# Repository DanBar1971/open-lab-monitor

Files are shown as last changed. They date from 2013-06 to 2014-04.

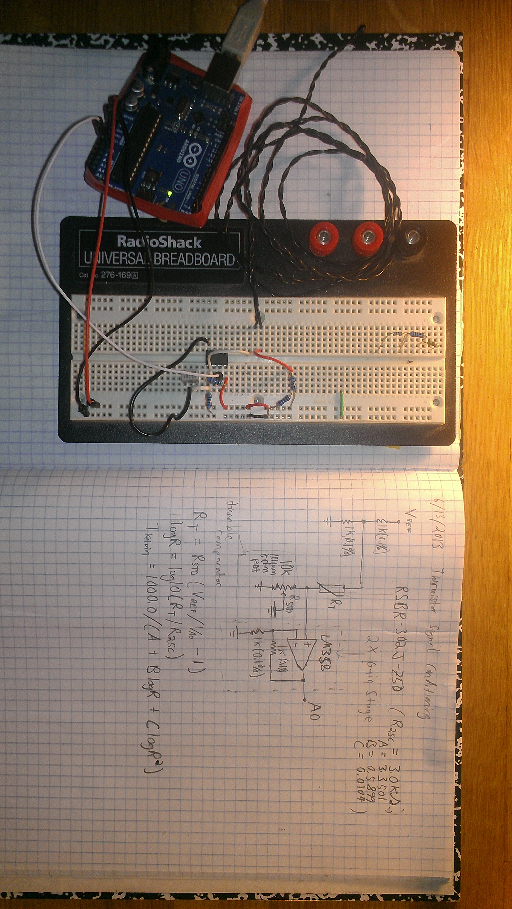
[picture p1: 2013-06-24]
pcb/reference/craigRoomBoardSchematic.jpg

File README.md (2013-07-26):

open-lab-monitor
=================

### Overview

An open hardware microcontroller device for use in research and teaching laboratory settings, and as an independent sensing node.

### PCB

- Nice reference for MAGJACK options:
http://mbed.org/cookbook/Ethernet-RJ45 
- Nice reference for uSD breakout schematic, adafruit:
https://raw.github.com/adafruit/MicroSD-breakout-board/master/usdbreakout.png
 
### Code

Code for controlling the Open Lab Monitor device, the development and goals and applications of which are documented [here](https://github.com/Pioneer-Valley-Open-Science/pioneer-valley-open-science.github.com/issues/8).

The code consists of Arduino code to be loaded on an Arduino-based sensor platform, as well as a Processing and Python interface for interacting with the platform (e.g. plotting sensor values, downloading data as a CSV file). 

#### Notes on the Arduino Code

Some non-standard Arduino libraries are required, frozen versions of which can be found [here](https://github.com/dwblair/open-lab-monitor/tree/master/arduino/libraries).  Copy (or better yet, link) the folders under "libraries" to your "libraries" folder for your Arduino sketchbook:

* ThermistorLib (cversek's library for reading thermistor values) -- latest version found [here](https://github.com/cversek/umass-physics/tree/master/teis/arduino/ThermistorLib).
                                                                  
* SerialCommand (originally Steven Cogswell's slick library for parsing commands over serial)  -- check out his surly [blog post](http://husks.wordpress.com/2011/05/23/a-minimal-arduino-library-for-processing-serial-commands/); we are using the new and improved version hosted on github [here](https://github.com/kroimon/Arduino-SerialCommand)

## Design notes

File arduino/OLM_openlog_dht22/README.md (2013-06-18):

## Resources

### DHT22 wiring diagram and Arduino library

You'll need the latest DHT22 library from Adafruit.  Find that [here](http://learn.adafruit.com/dht), as well as a tutorial re: how to hook up the sensor.

### Ethercard Arduino Library from JeeLabs

You'll need the latest Ethercard library.  Find that [here](https://github.com/jcw/ethercard).

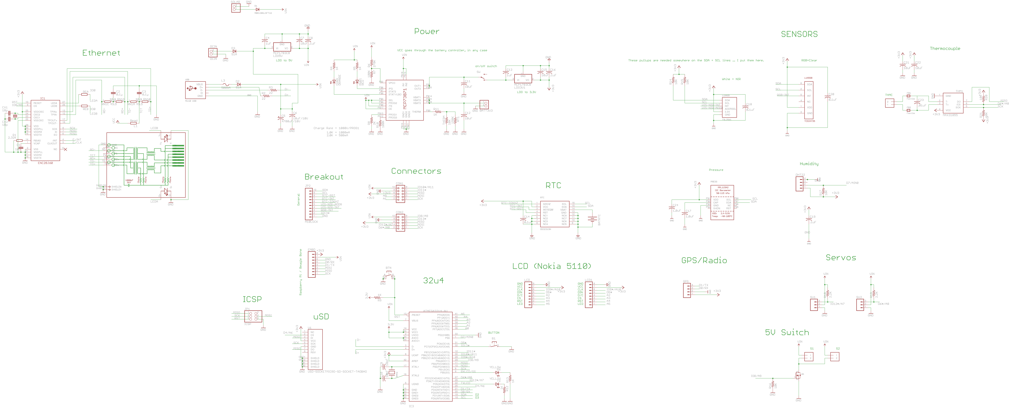
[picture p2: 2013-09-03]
pcb/eagle/olm-base-rev4.png

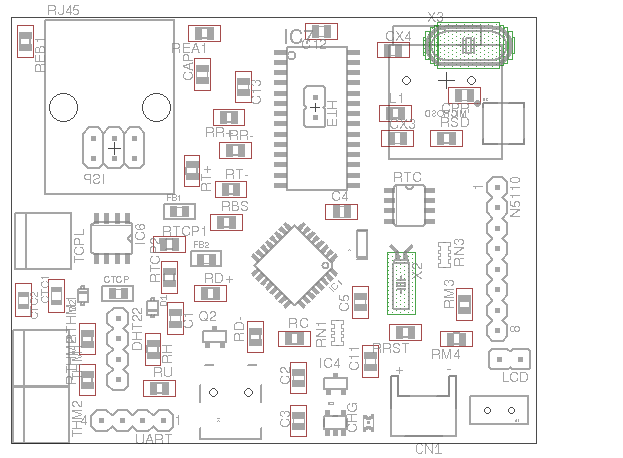
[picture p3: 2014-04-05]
pcb/eagle/VUSB/open-lab-VUSB-A.png

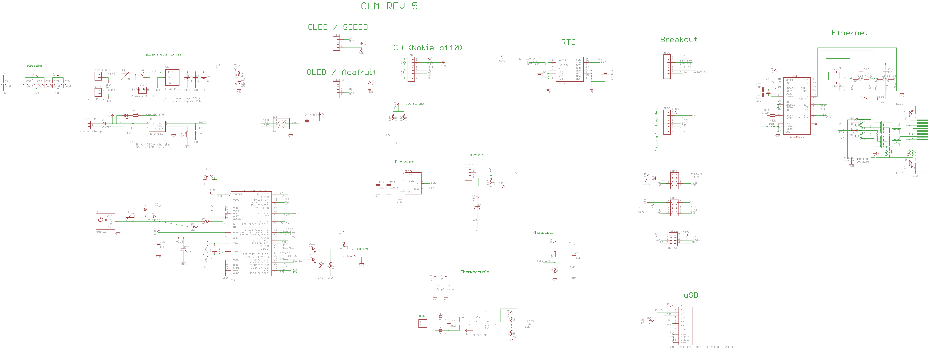
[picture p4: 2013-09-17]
pcb/eagle/OLM-REV-5.png

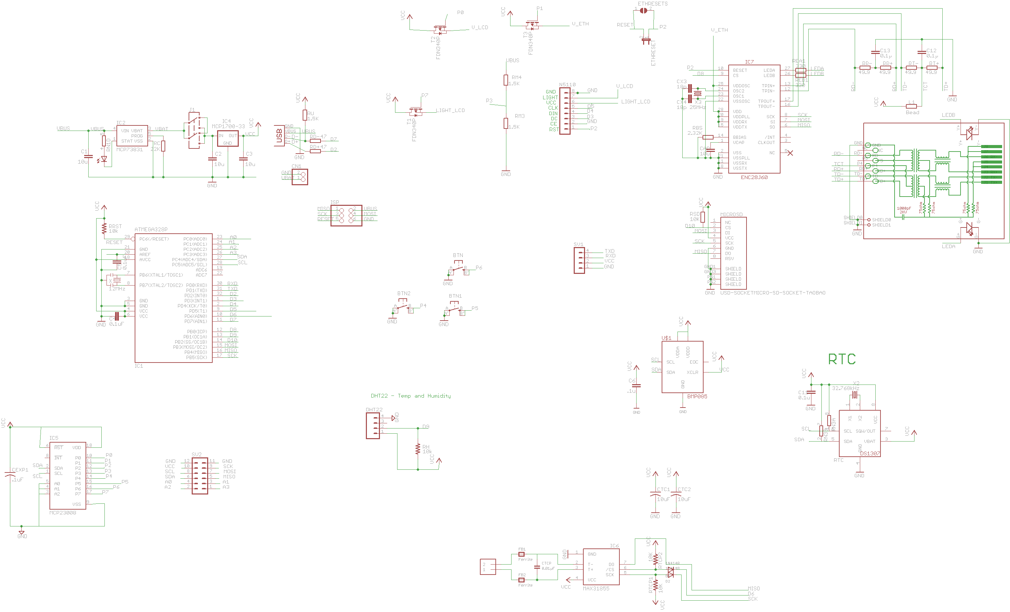
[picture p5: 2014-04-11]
pcb/eagle/VUSB/open-lab-VUSB-A-schem.png

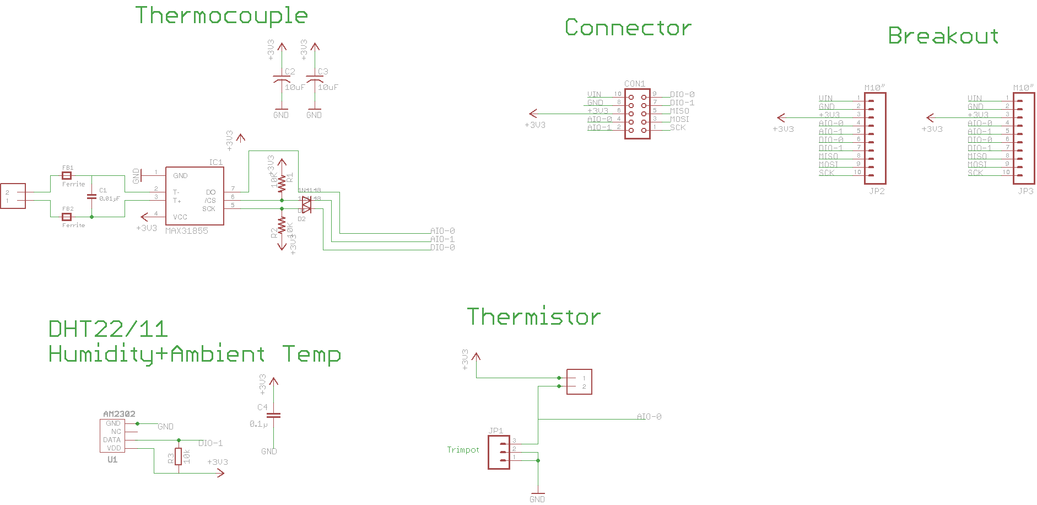
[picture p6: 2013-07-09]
pcb/eagle/OLM-sensorBoardA.png

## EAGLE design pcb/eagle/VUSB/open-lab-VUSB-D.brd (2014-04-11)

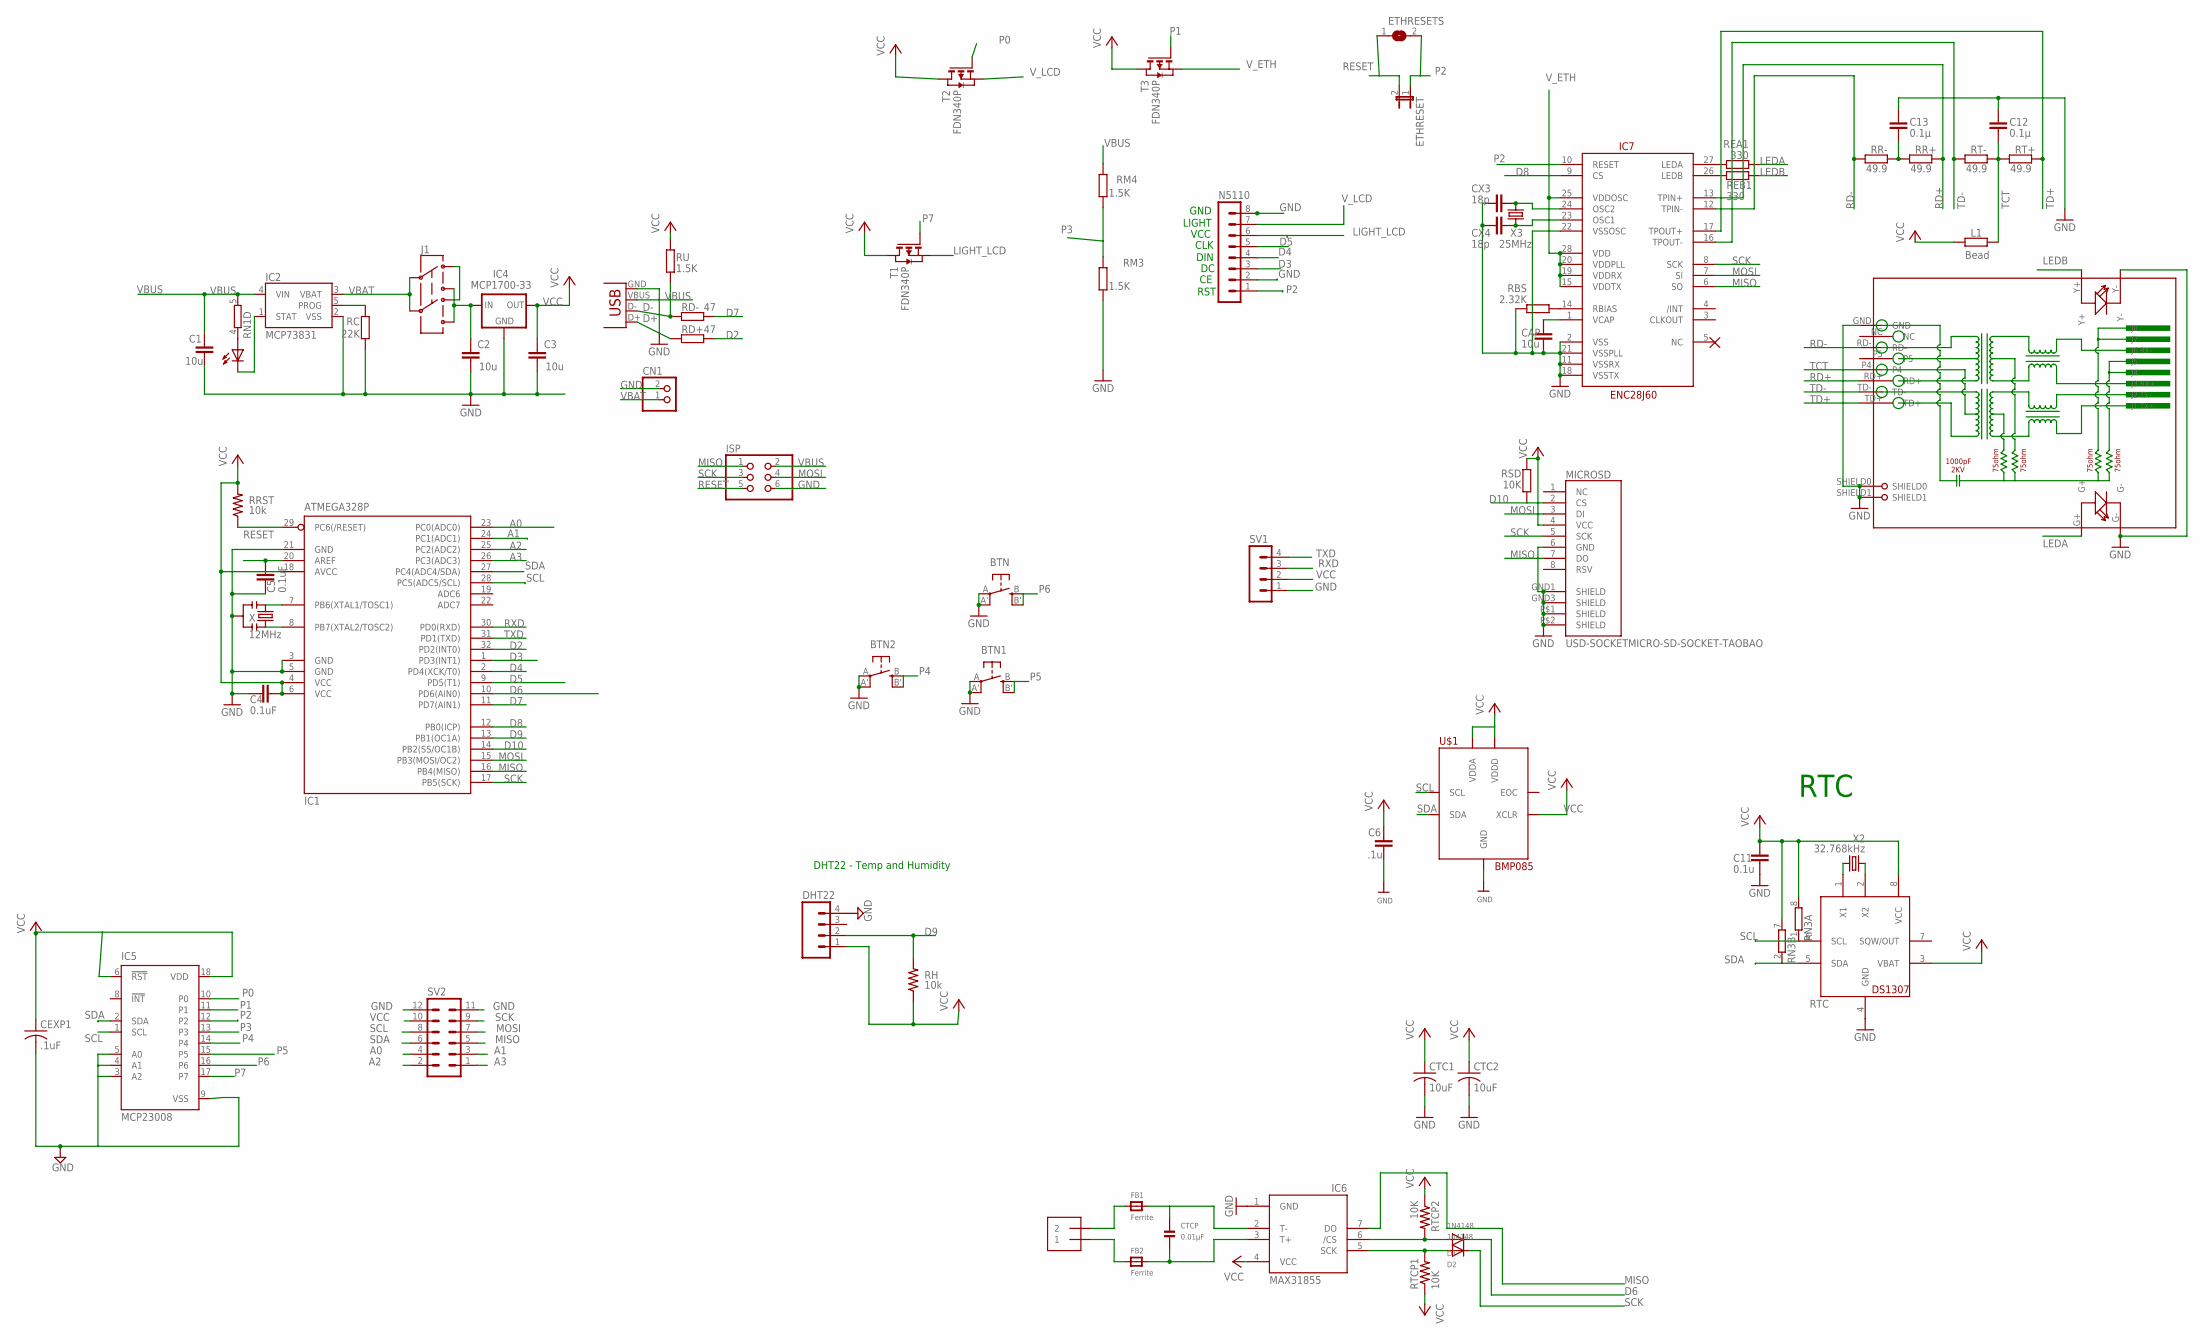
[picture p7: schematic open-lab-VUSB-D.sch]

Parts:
BTN, BTN1, BTN2: EVQQ2; EVQ-Q2
C1, C2, C3: 10u; C0805
C4, C5: 0.1uF; C0805
C6: .1u; C0805
C11: 0.1u; C0805
C12, C13: 0.1µ; C0805
CAP: 10u; C0805
CEXP1: .1uF; C0805K
CHG: 0805; CHIPLED_0805
CN1: JST_2PIN-SMT-RA; JST-PH-2-SMT-RA
CTC1, CTC2: 10uF; C0805K
CTCP: 0.01µF; _0805
CX3, CX4: 18p; C0805
D1: 1N4148; SOD-323F
D2: 1n4148; SOD-323F
DHT22: M04LOCK; 1X04_LOCK
ETHRESET: JP1E; JP1
ETHRESETS: SJ
FB1, FB2: Ferrite; _0805
IC1: ATMEGA328P; TQFP32-08
IC2: MCP73831; SOT23-5
IC4: MCP1700-33; SOT23
IC5: MCP23008; SO18W
IC6: MAX31855; SO08
IC7: ENC28J60; SOIC28WLONG
ISP: PINHD-2X3; 2X03
J1: AYZ0202
L1: Bead; R0805
MICROSD: USD-SOCKETMICRO-SD-SOCKET-TAOBAO; MICRO-SD-SOCKET-TAOBAO
N5110: MA08-1
RBS: 2.32K; R0805
RC: 22K; R0805
RD+: 47; R0805
RD-: 47; R0805
REA1: 330; R0805
REB1: 330; R0805
RH: 10k; R0805@1
RJ45: HR911105A
RM3, RM4: 1.5K; R0805
RN1, RN3: 4R-NEXB38V; EXB38V
RR+: 49.9; R0805
RR-: 49.9; R0805
RRST: 10k; R0805@1
RSD: 10K; R0805
RT+: 49.9; R0805
RT-: 49.9; R0805
RTC: DS1307; SO08
RTCP1, RTCP2: 10K; R0805
RU: 1.5K; R0805
SV1: MA04-1
SV2: MA06-2
T1, T2, T3: FDN340P; SOT-23
TCPL: 1X2-3.5MM
U$1: BMP085
X: 12MHz; RESONATOR-SMD
X1: USBSMD; USB-MINIB
X2: 32.768kHz; TC26H
X3: 25MHz; HC49U-V

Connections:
A0: IC1.23 (PC0(ADC0)), SV2.4
A1: IC1.24 (PC1(ADC1)), SV2.3
A2: IC1.25 (PC2(ADC2)), SV2.2
A3: IC1.26 (PC3(ADC3)), SV2.1
AREF: C5.2, IC1.20 (AREF)
CS: D1.A, IC6.6 (/CS), RTCP2.2
D2: IC1.32 (PD2(INT0)), RD+.2
D3: IC1.1 (PD3(INT1)), N5110.3
D4: IC1.2 (PD4(XCK/T0)), N5110.4
D5: IC1.9 (PD5(T1)), N5110.5
D6: D1.C, IC1.10 (PD6(AIN0))
D7: IC1.11 (PD7(AIN1)), RD-.2
D8: IC1.12 (PB0(ICP)), IC7.9 (CS)
D9: DHT22.2, IC1.13 (PB1(OC1A)), RH.2
D10: IC1.14 (PB2(SS/OC1B)), MICROSD.2 (CS), RSD.1
D+: RD+.1, X1.D+
D-: RD-.1, RU.1, X1.D-
GND: BTN.A, BTN.A' (P1), BTN1.A, BTN1.A' (P1), BTN2.A, BTN2.A' (P1), C1.2, C2.2, C3.2, C4.1, C5.1, C6.2, C11.2, C12.1, C13.1, CAP.2, CEXP1.2, CN1.2 (1), CTC1.2, CTC2.2, CX3.2, CX4.2, DHT22.4, IC1.3 (GND), IC1.5 (GND), IC1.21 (GND), IC2.2 (VSS), IC4.1 (GND), IC5.3 (A2), IC5.4 (A1), IC5.5 (A0), IC5.9 (VSS), IC6.1 (GND), IC7.2 (VSS), IC7.11 (VSSRX), IC7.18 (VSSTX), IC7.21 (VSSPLL), IC7.22 (VSSOSC), ISP.6, MICROSD.6 (GND), MICROSD.GND1 (SHIELD), MICROSD.GND3 (SHIELD), MICROSD.P$1 (SHIELD), MICROSD.P$2 (SHIELD), N5110.2, N5110.8, RBS.1, RC.1, RJ45.G-, RJ45.GND, RJ45.SHIELD0, RJ45.SHIELD1, RJ45.Y-, RM3.1, RTC.4 (GND), SV1.1, SV2.11, SV2.12, U$1.P$1 (GND), X.2, X1.GND
LEDA: REA1.2, RJ45.G+
LEDB: REB1.2, RJ45.Y+
LIGHT_LCD: N5110.6, T1.2 (S)
MISO: IC1.16 (PB4(MISO)), IC6.7 (DO), IC7.6 (SO), ISP.1, MICROSD.7 (DO), SV2.5
MOSI: IC1.15 (PB3(MOSI/OC2)), IC7.7 (SI), ISP.4, MICROSD.3 (DI), SV2.7
unnamed: J1.3 (1), J1.6 (4)
unnamed: IC1.7 (PB6(XTAL1/TOSC1)), X.1
unnamed: IC1.8 (PB7(XTAL2/TOSC2)), X.3
unnamed: CHG.C, IC2.1 (STAT)
unnamed: IC2.5 (PROG), RC.2
unnamed: FB1.1, TCPL.2
unnamed: CTCP.1, FB1.2, IC6.2 (T-)
unnamed: CHG.A, RN1.4 (1)
unnamed: FB2.1, TCPL.1
unnamed: CTCP.2, FB2.2, IC6.3 (T+)
unnamed: RTC.1 (X1), X2.2
unnamed: RTC.2 (X2), X2.1
unnamed: IC7.27 (LEDA), REA1.1
unnamed: IC7.26 (LEDB), REB1.1
unnamed: CAP.1, IC7.1 (VCAP)
unnamed: CX3.1, IC7.24 (OSC2), X3.2
unnamed: CX4.1, IC7.23 (OSC1), X3.1
unnamed: C13.2, RR+.2, RR-.1
unnamed: IC7.14 (RBIAS), RBS.2
P0: IC5.10 (P0), T2.3 (G)
P1: IC5.11 (P1), T3.3 (G)
P2: ETHRESET.1, ETHRESETS.2, IC5.12 (P2), IC7.10 (RESET), N5110.1
P3: IC5.13 (P3), RM3.2, RM4.1
P4: BTN2.B (S), BTN2.B' (S1), IC5.14 (P4)
P5: BTN1.B (S), BTN1.B' (S1), IC5.15 (P5)
P6: BTN.B (S), BTN.B' (S1), IC5.16 (P6)
P7: IC5.17 (P7), T1.3 (G)
RD+: IC7.13 (TPIN+), RJ45.RD+, RR+.1
RD-: IC7.12 (TPIN-), RJ45.RD-, RR-.2
RESET: ETHRESET.2, ETHRESETS.1, IC1.29 (PC6(/RESET)), ISP.5, RRST.1
RXD: IC1.30 (PD0(RXD)), SV1.3
SCK: D2.C, IC1.17 (PB5(SCK)), IC7.8 (SCK), ISP.3, MICROSD.5 (SCK), SV2.9
SCK1: D2.A, IC6.5 (SCK), RTCP1.2
SCL: IC1.28 (PC5(ADC5/SCL)), IC5.1 (SCL), RN3.1, RTC.6 (SCL), SV2.8, U$1.P$6 (SCL)
SDA: IC1.27 (PC4(ADC4/SDA)), IC5.2 (SDA), RN3.2 (1), RTC.5 (SDA), SV2.6, U$1.P$7 (SDA)
TCT: C12.2, L1.1, RJ45.P4, RT+.2, RT-.1
TD+: IC7.17 (TPOUT+), RJ45.TD+, RT+.1
TD-: IC7.16 (TPOUT-), RJ45.TD-, RT-.2
TXD: IC1.31 (PD1(TXD)), SV1.4
VBAT: CN1.1 (2), IC2.3 (VBAT), J1.2, J1.5
VBUS: C1.1, IC2.4 (VIN), ISP.2, RM4.2, RN1.5 (2), X1.VBUS
VCC: C3.1, C4.2, C6.1, C11.1, CEXP1.1, CTC1.1, CTC2.1, DHT22.1, IC1.4 (VCC), IC1.6 (VCC), IC1.18 (AVCC), IC4.2 (OUT), IC5.6 (!RST), IC5.18 (VDD), IC6.4 (VCC), L1.2, MICROSD.4 (VCC), RH.1, RN3.7 (2), RN3.8 (2), RRST.2, RSD.2, RTC.3 (VBAT), RTC.8 (VCC), RTCP1.1, RTCP2.1, RU.2, SV1.2, SV2.10, T1.1 (D), T2.1 (D), T3.1 (D), U$1.P$3 (VDDA), U$1.P$4 (VDDD), U$1.P$8 (XCLR)
VDD: C2.1, IC4.3 (IN), J1.1 (3), J1.4 (6)
V_ETH: IC7.15 (VDDTX), IC7.19 (VDDRX), IC7.20 (VDDPLL), IC7.25 (VDDOSC), IC7.28 (VDD), T3.2 (S)
V_LCD: N5110.7, T2.2 (S)

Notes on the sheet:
RST
DIN
CLK
VCC
LIGHT
GND
RTC
DHT22 - Temp and Humidity

Board: 2 copper layers, 72 parts (4 on the bottom side), 68 nets, no tracks yet.

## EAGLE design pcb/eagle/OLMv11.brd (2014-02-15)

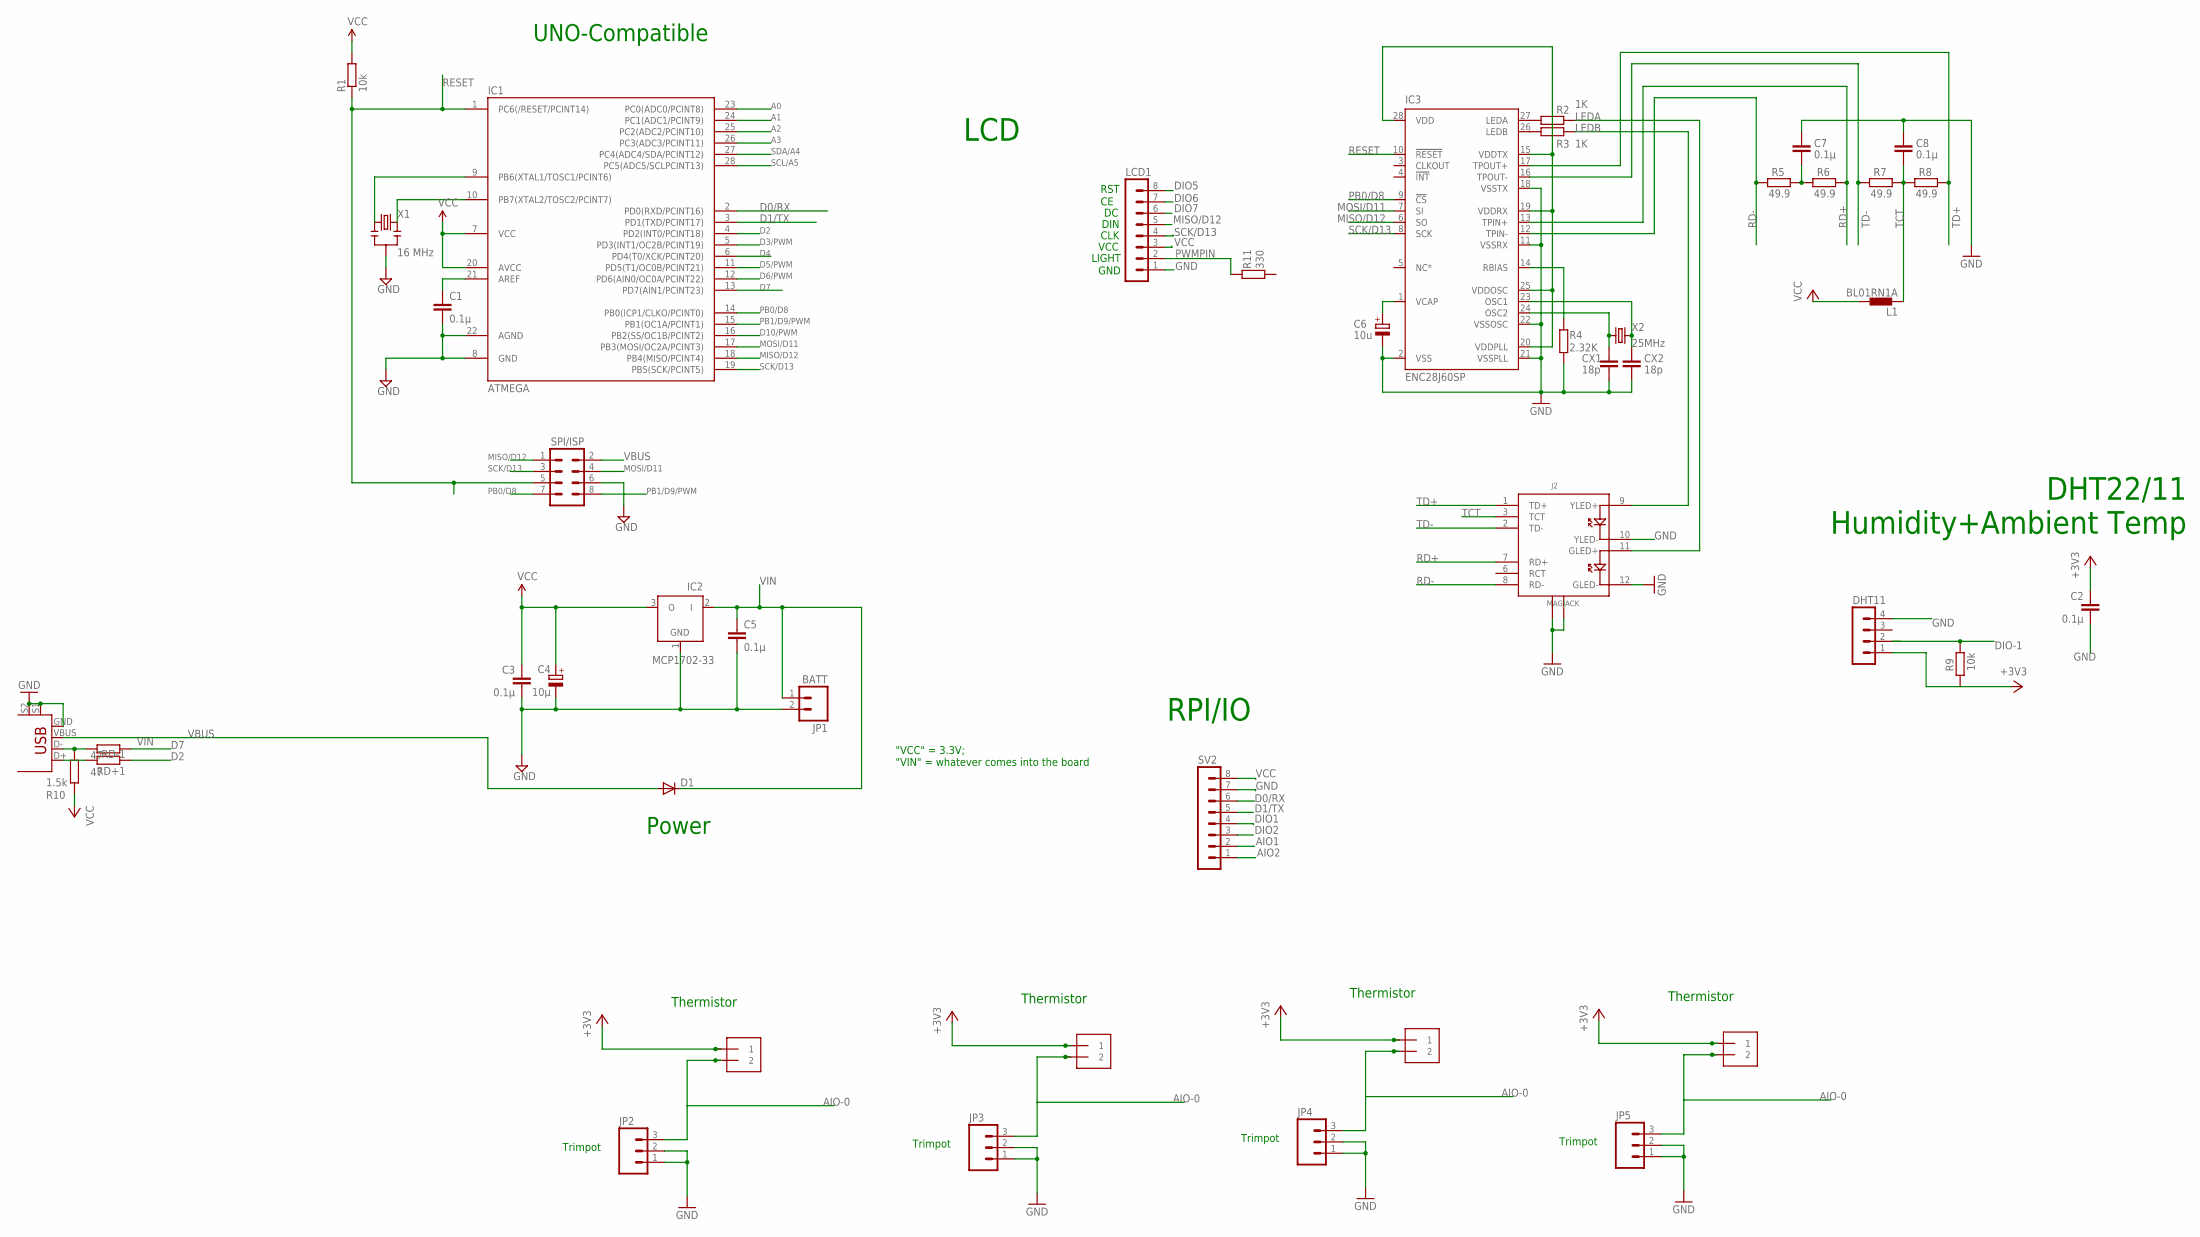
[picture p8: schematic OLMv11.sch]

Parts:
C1, C2, C3, C5, C7, C8: 0.1µ; C025-024X044
C4: 10µ; E1,8-4
C6: 10u; E1,8-4
CX1, CX2: 18p; C025-024X044
D1: DIODE-D-5; D-5
DHT11: MA04-1
IC1: ATMEGA; DIL28-3
IC2: MCP1702-33; TO92
IC3: ENC28J60SP; DIL28-3
J1, J3, J4, J5: 1X2-3.5MM
J2: MAGJACK
JP1: BATT; 1X02_LOCK_LONGPADS
JP2, JP3, JP4, JP5: M03PTH; 1X03
L1: BL01RN1A
LCD1: MA08-1
R1, R9: 10k; 0204/7
R2, R3: 1K; 0204/7
R4: 2.32K; 0204/7
R5, R6, R7, R8: 49.9; 0204/7
R10: 1.5k; 0204/7
R11: 330; 0204/7
RD+1: 47; 0204/7
RD-1: 47; 0204/7
SV1: SPI/ISP; MA04-2
SV2: MA08-1
USB: USB+SHIELD; USB-B-PTH
X1: 16 MHz; RESONATOR-PTH
X2: 25MHz; HC49US

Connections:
+3V3: C2.1, DHT11.1, J1.1, J3.1, J4.1, J5.1, R9.1
A0: IC1.23 (PC0(ADC0/PCINT8))
A1: IC1.24 (PC1(ADC1/PCINT9))
A2: IC1.25 (PC2(ADC2/PCINT10))
A3: IC1.26 (PC3(ADC3/PCINT11))
AIO1: SV2.2
AIO2: SV2.1
AIO-0: J1.2, J3.2, J4.2, J5.2, JP2.3, JP3.3, JP4.3, JP5.3
D0/RX: IC1.2 (PD0(RXD/PCINT16)), SV2.6
D1/TX: IC1.3 (PD1(TXD/PCINT17)), SV2.5
D2: IC1.4 (PD2(INT0/PCINT18)), RD+1.1
D3/PWM: IC1.5 (PD3(INT1/OC2B/PCINT19))
D4: IC1.6 (PD4(T0/XCK/PCINT20))
D5/PWM: IC1.11 (PD5(T1/OC0B/PCINT21))
D6/PWM: IC1.12 (PD6(AIN0/OC0A/PCINT22))
D7: IC1.13 (PD7(AIN1/PCINT23)), RD-1.1
D10/PWM: IC1.16 (PB2(SS/OC1B/PCINT2))
DIO1: SV2.4
DIO2: SV2.3
DIO5: LCD1.8
DIO6: LCD1.7
DIO7: LCD1.6
DIO-1: DHT11.2, R9.2
GND: C1.2, C2.2, C3.2, C4.-, C5.2, C6.-, C7.1, C8.1, CX1.2, CX2.2, DHT11.4, IC1.8 (GND), IC1.22 (AGND), IC2.1 (GND), IC3.2 (VSS), IC3.11 (VSSRX), IC3.18 (VSSTX), IC3.21 (VSSPLL), IC3.22 (VSSOSC), J2.10 (YLED-), J2.12 (GLED-), J2.M1 (GND1), J2.M2 (GND2), JP1.2, JP2.1, JP2.2, JP3.1, JP3.2, JP4.1, JP4.2, JP5.1, JP5.2, LCD1.1, R4.2, SV1.6, SV2.7, USB.GND, USB.S1, USB.S2, X1.2
LEDA: J2.11 (GLED+), R2.2
LEDB: J2.9 (YLED+), R3.2
MISO/D12: IC1.18 (PB4(MISO/PCINT4)), IC3.6 (SO), LCD1.5, SV1.1
MOSI/D11: IC1.17 (PB3(MOSI/OC2A/PCINT3)), IC3.7 (SI), SV1.4
unnamed: IC1.9 (PB6(XTAL1/TOSC1/PCINT6)), X1.1
unnamed: C1.1, IC1.21 (AREF)
unnamed: IC1.10 (PB7(XTAL2/TOSC2/PCINT7)), X1.3
unnamed: IC3.27 (LEDA), R2.1
unnamed: RD+1.2, USB.D+
unnamed: IC3.26 (LEDB), R3.1
unnamed: R10.1, RD-1.2, USB.D-
unnamed: C6.+, IC3.1 (VCAP)
unnamed: IC3.14 (RBIAS), R4.1
unnamed: CX1.1, IC3.24 (OSC2), X2.1
unnamed: CX2.1, IC3.23 (OSC1), X2.2
unnamed: C7.2, R5.2, R6.1
PB0/D8: IC1.14 (PB0(ICP1/CLKO/PCINT0)), IC3.9 (!CS), SV1.7
PB1/D9/PWM: IC1.15 (PB1(OC1A/PCINT1)), SV1.8
PWMPIN: LCD1.2
RD+: IC3.13 (TPIN+), J2.7 (RD+), R6.2
RD-: IC3.12 (TPIN-), J2.8 (RD-), R5.1
RESET: IC1.1 (PC6(/RESET/PCINT14)), IC3.10 (!RESET), R1.1, SV1.5
SCK/D13: IC1.19 (PB5(SCK/PCINT5)), IC3.8 (SCK), LCD1.4, SV1.3
SCL/A5: IC1.28 (PC5(ADC5/SCLPCINT13))
SDA/A4: IC1.27 (PC4(ADC4/SDA/PCINT12))
TCT: C8.2, J2.3 (TCT), L1.1, R7.2, R8.1
TD+: IC3.17 (TPOUT+), J2.1 (TD+), R8.2
TD-: IC3.16 (TPOUT-), J2.2 (TD-), R7.1
VBUS: D1.A, SV1.2
VCC: C3.1, C4.+, IC1.7 (VCC), IC1.20 (AVCC), IC2.3 (O), IC3.15 (VDDTX), IC3.19 (VDDRX), IC3.20 (VDDPLL), IC3.25 (VDDOSC), IC3.28 (VDD), L1.2, LCD1.3, R1.2, R10.2, SV2.8
VIN: C5.1, D1.C, IC2.2 (I), JP1.1, USB.VBUS

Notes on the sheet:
UNO-Compatible
Power
"VCC" = 3.3V; "VIN" = whatever comes into the board
Thermistor
DHT22/11 Humidity+Ambient Temp
Trimpot
LCD
RPI/IO
RST
DIN
CLK
VCC
LIGHT
GND

Board: 2 copper layers, 45 parts (0 on the bottom side), 36 nets, no tracks yet.

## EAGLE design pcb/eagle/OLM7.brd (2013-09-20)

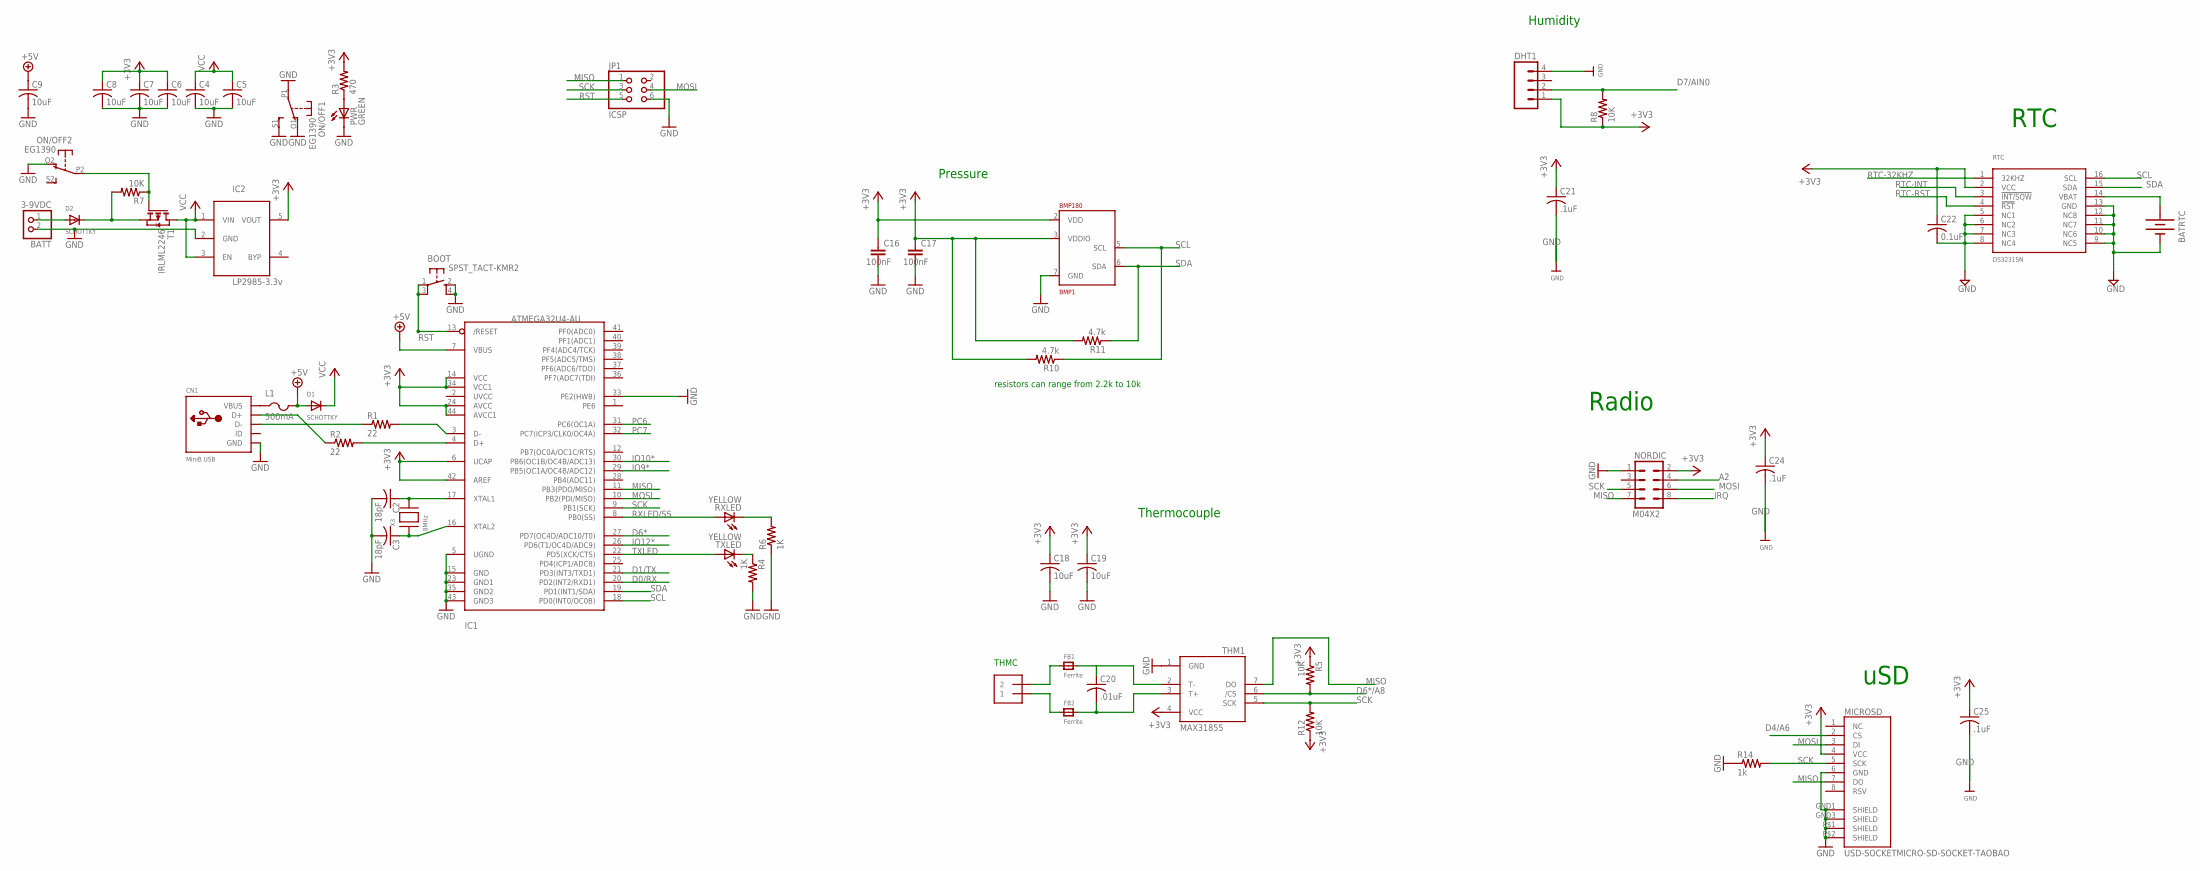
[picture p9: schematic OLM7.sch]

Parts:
BATRTC: BATTERYBATTERY_12MM_SMT; BATTCON_12MM_SMT
BATT: 3-9VDC; JST-PH-2-SMT-RA
BMP1: BMP180; LGA7
BOOT: SPST_TACT-KMR2; KMR2
C2, C3: 18pF; C0805K
C4, C5, C6, C7, C8, C9: 10uF; C0805K
C16, C17: 100nF; C0805
C18, C19: 10uF; C0805
C20: .01uF; C0805
C21, C24, C25: .1uF; C0805
C22: 0.1uF; C0805
CN1: MiniB USB; USB-MINIB_LARGER
D1, D2: SCHOTTKY; SOD-123
DHT1: M04LOCK; 1X04_LOCK
FB1, FB2: Ferrite; _0805
IC1: ATMEGA32U4-AU; TQFP44
IC2: LP2985-3.3v; SOT23-5L
JP1: ICSP; 2X03
L1: 500mA; R1206
MICROSD: USD-SOCKETMICRO-SD-SOCKET-TAOBAO; MICRO-SD-SOCKET-TAOBAO
NORDIC: M04X2; 2X4
ON/OFF: EG1390
PWR: GREEN; CHIPLED_0805
R1, R2: 22; R0805
R3: 470; R0805
R4, R6: 1K; R0805
R5, R7, R8, R12: 10K; R0805
R10, R11: 4.7k; R0805
R14: 1k; R0805
RTC: DS3231SN; SO16W
RXLED: YELLOW; CHIPLED_0805
T1: IRLML2246; SOT-23
THM1: MAX31855; SO08
THMC: 1X2-3.5MM
TXLED: YELLOW; CHIPLED_0805
X3: 8MHz; NX5032

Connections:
+3V3: BMP1.2 (VDD), BMP1.3 (VDDIO), C6.1, C7.1, C8.1, C16.1, C17.1, C18.1, C19.1, C21.1, C22.1, C24.1, C25.1, DHT1.1, IC1.6 (UCAP), IC1.14 (VCC), IC1.24 (AVCC), IC1.34 (VCC1), IC1.42 (AREF), IC1.44 (AVCC1), IC2.5 (VOUT), MICROSD.4 (VCC), NORDIC.2, R3.2, R5.1, R8.1, R10.2, R11.2, R12.1, RTC.2 (VCC), THM1.4 (VCC)
+5V: C9.1, D1.A, IC1.7 (VBUS), L1.2
A2: NORDIC.4
D0/RX: IC1.20 (PD2(INT2/RXD1))
D1/TX: IC1.21 (PD3(INT3/TXD1))
D4/A6: MICROSD.2 (CS)
D6*: IC1.27 (PD7(OC4D/ADC10/T0))
D6*/A8: R5.2, THM1.6 (/CS)
D7/AIN0: DHT1.2, R8.2
GND: BATRTC.P$1 (-), BATT.2 (1), BMP1.7 (GND), BOOT.2 (S), BOOT.4 (S1), C2.2, C3.2, C4.2, C5.2, C6.2, C7.2, C8.2, C9.2, C16.2, C17.2, C18.2, C19.2, C21.2, C22.2, C24.2, C25.2, CN1.GND, DHT1.4, IC1.5 (UGND), IC1.15 (GND), IC1.23 (GND1), IC1.33 (PE2(HWB)), IC1.35 (GND2), IC1.43 (GND3), IC2.2 (GND), JP1.6, MICROSD.6 (GND), MICROSD.GND1 (SHIELD), MICROSD.GND3 (SHIELD), MICROSD.P$1 (SHIELD), MICROSD.P$2 (SHIELD), NORDIC.1, ON/OFF.O1 (O), ON/OFF.O2 (O), ON/OFF.P1, ON/OFF.S1 (S), PWR.C, R4.2, R6.1, R14.1, RTC.5 (NC1), RTC.6 (NC2), RTC.7 (NC3), RTC.8 (NC4), RTC.9 (NC5), RTC.10 (NC6), RTC.11 (NC7), RTC.12 (NC8), RTC.13 (GND), THM1.1 (GND)
IO9*: IC1.29 (PB5(OC1A/OC4B/ADC12))
IO10*: IC1.30 (PB6(OC1B/OC4B/ADC13))
IO12*: IC1.26 (PD6(T1/OC4D/ADC9))
IRQ: NORDIC.8
MISO: IC1.11 (PB3(PDO/MISO)), JP1.1, MICROSD.7 (DO), NORDIC.7, THM1.7 (DO)
MOSI: IC1.10 (PB2(PDI/MISO)), JP1.4, MICROSD.3 (DI), NORDIC.6
unnamed: PWR.A, R3.1
unnamed: CN1.D+, R2.1
unnamed: IC1.3 (D-), R1.2
unnamed: IC1.4 (D+), R2.2
unnamed: CN1.D-, R1.1
unnamed: D2.C, R7.2, T1.2 (S)
unnamed: BATT.1 (2), D2.A
unnamed: C2.1, IC1.17 (XTAL1), X3.P$2
unnamed: C3.1, IC1.16 (XTAL2), X3.P$1
unnamed: R4.1, TXLED.C
unnamed: R6.2, RXLED.C
unnamed: ON/OFF.P2, R7.1, T1.3 (G)
unnamed: BATRTC.P$2 (+), RTC.14 (VBAT)
unnamed: FB1.1, THMC.2
unnamed: C20.1, FB1.2, THM1.2 (T-)
unnamed: FB2.1, THMC.1
unnamed: C20.2, FB2.2, THM1.3 (T+)
PC6: IC1.31 (PC6(OC1A))
PC7: IC1.32 (PC7(ICP3/CLK0/OC4A))
RST: BOOT.1, BOOT.3 (P1), IC1.13 (/RESET), JP1.5
RTC-32KHZ: RTC.1 (32KHZ)
RTC-INT: RTC.3 (!INT/SQW)
RTC-RST: RTC.4 (!RST)
RXLED/SS: IC1.8 (PB0(SS)), RXLED.A
SCK: IC1.9 (PB1(SCK)), JP1.3, MICROSD.5 (SCK), NORDIC.5, R12.2, THM1.5 (SCK)
SCK1: R14.2
SCL: BMP1.5 (SCL), IC1.18 (PD0(INT0/OC0B)), R10.1, RTC.16 (SCL)
SDA: BMP1.6 (SDA), IC1.19 (PD1(INT1/SDA)), R11.1, RTC.15 (SDA)
TXLED: IC1.22 (PD5(XCK/CTS)), TXLED.A
VBUS: CN1.VBUS, L1.1
VCC: C4.1, C5.1, D1.C, IC2.1 (VIN), IC2.3 (EN), T1.1 (D)

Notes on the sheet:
Pressure
resistors can range from 2.2k to 10k
Thermocouple
THMC
Humidity
Radio
RTC
uSD

Board: 2 copper layers, 54 parts (0 on the bottom side), 32 nets, no tracks yet.

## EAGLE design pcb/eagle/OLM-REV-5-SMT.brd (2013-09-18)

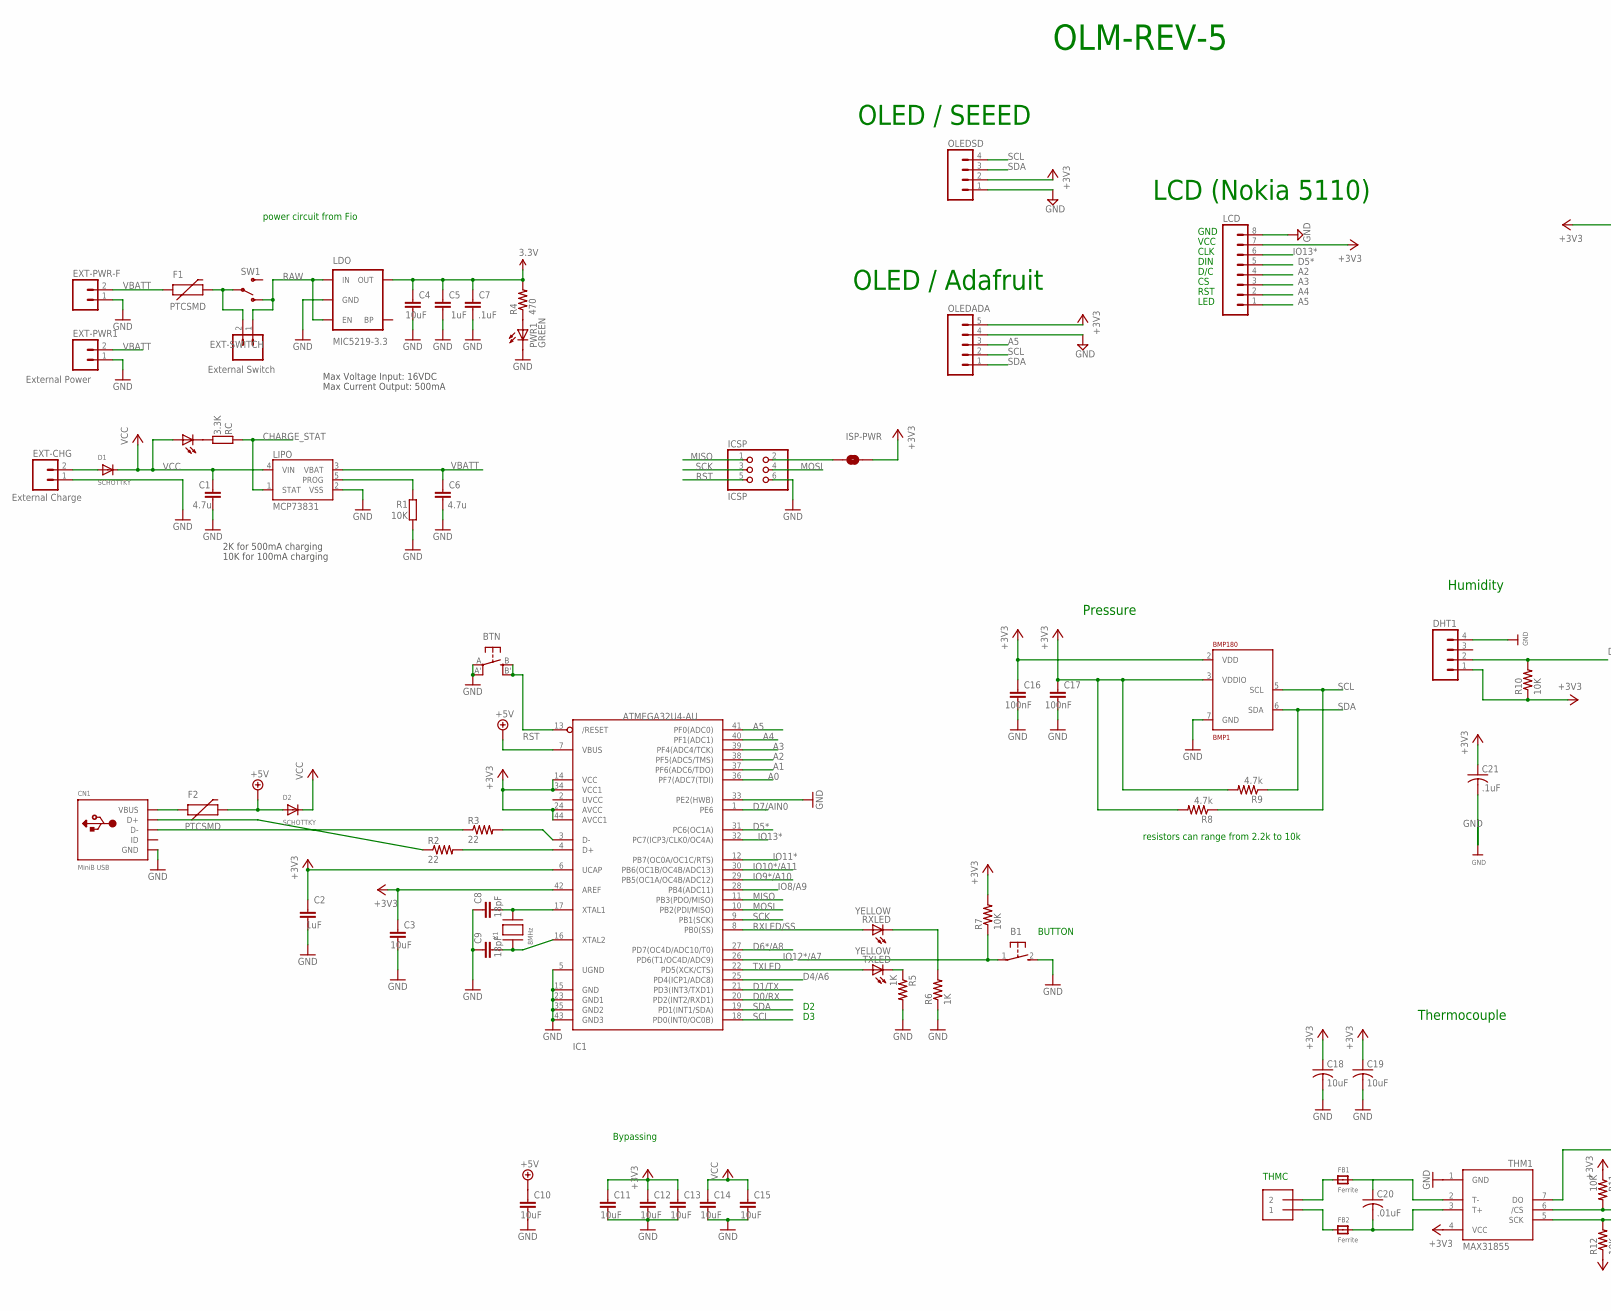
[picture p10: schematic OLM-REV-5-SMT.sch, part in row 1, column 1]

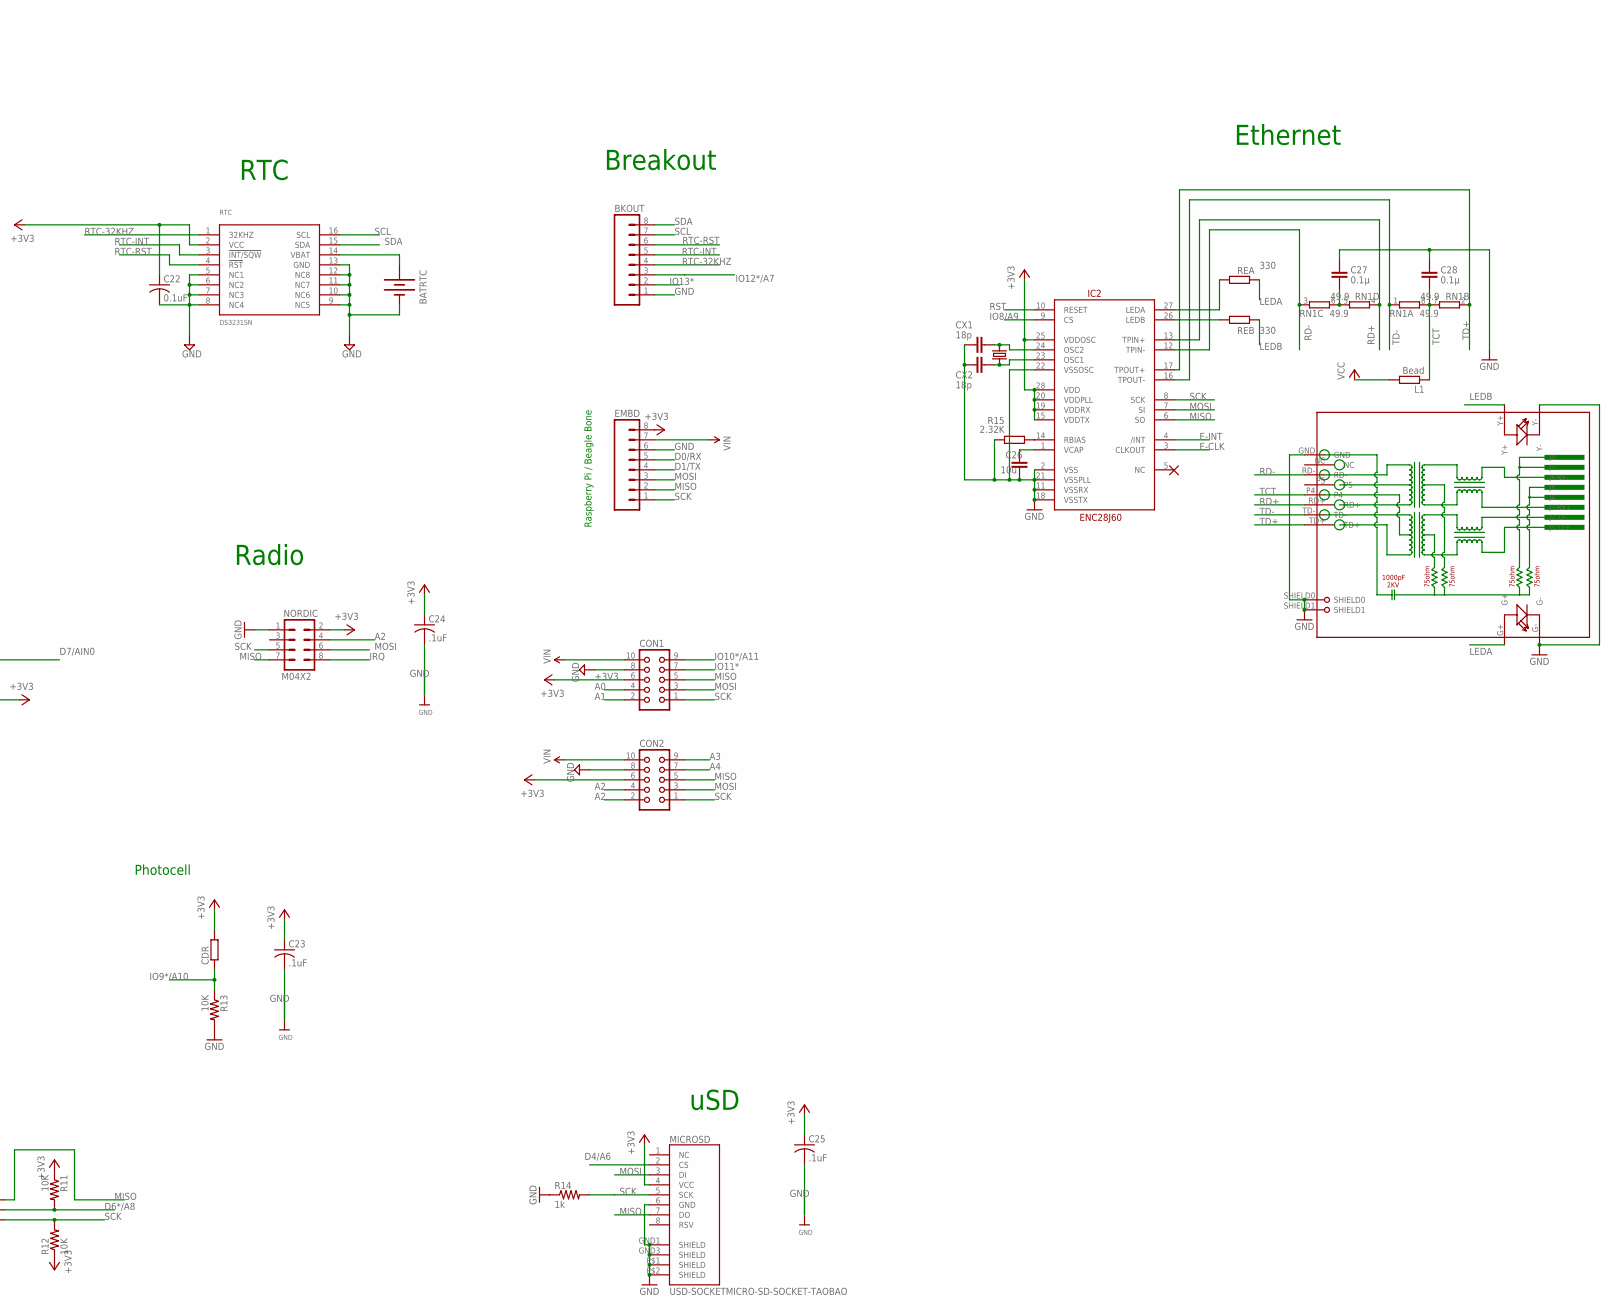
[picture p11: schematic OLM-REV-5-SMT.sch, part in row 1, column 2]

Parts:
B1: 31-XX; B3F-31XX
BATRTC: BATTERYBATTERY_12MM_SMT; BATTCON_12MM_SMT
BKOUT: M08LOCK; 1X08_LOCK
BMP1: BMP180; LGA7
BTN: EVQQ2; EVQ-Q2
C1, C6: 4.7u; C0805
C2, C5: 1uF; C0805
C3, C4, C10, C11, C12, C13, C14, C15, C18, C19: 10uF; C0805
C7, C21, C23, C24, C25: .1uF; C0805
C8, C9: 18pF; C0805
C16, C17: 100nF; C0805
C20: .01uF; C0805
C22: 0.1uF; C0805
C26: 10u; C0805
C27, C28: 0.1µ; C0805
CDR: R-EU_0204/7; 0204/7
CHG1: 0805; CHIPLED_0805
CN1: MiniB USB; USB-MINIB_LARGER
CON1, CON2: CON10L
CX1, CX2: 18p; C0805
D1, D2: SCHOTTKY; SOD-123
DHT1: M04LOCK; 1X04_LOCK
EMBD: M08LOCK; 1X08_LOCK
EXT-CHG: External Charge; 1X02
EXT-PWR1: External Power; 1X02
EXT-PWR-F: M02-JST-2MM-SMT; JST-2-SMD
EXT-SWITCH: External Switch; 1X02
EXTL: 25MHz; CRYSTAL-SMD-10.5X4.8-2PIN
F1, F2: PTCSMD; PTC-1206
FB1, FB2: Ferrite; _0805
IC1: ATMEGA32U4-AU; TQFP44
IC2: ENC28J60; SOIC28WLONG
ICSP: ICSP; 2X03
ISP-PWR: SOLDERJUMPERTRACE; SJ_2S-TRACE
L1: Bead; R0805
LCD: M08LOCK; 1X08_LOCK
LDO: MIC5219-3.3; SOT23-5
LIPO: MCP73831; SOT23-5
MICROSD: USD-SOCKETMICRO-SD-SOCKET-TAOBAO; MICRO-SD-SOCKET-TAOBAO
NORDIC: M04X2; 2X4
OLEDADA: M05LOCK; 1X05_LOCK
OLEDSD: M04LOCK; 1X04_LOCK
PWR1: GREEN; CHIPLED_0805
R1, R7, R10, R11, R12, R13: 10K; R0805
R2, R3: 22; R0805
R4: 470; R0805
R5, R6: 1K; R0805
R8, R9: 4.7k; R0805
R14: 1k; R0805
R15: 2.32K; R0805
RC: 3.3K; R0805
REA: 330; R0805
REB: 330; R0805
RJ1: HR911105A
RN1: 49.9; EXB38V
RTC: DS3231SN; SO16W
RXLED: YELLOW; CHIPLED_0805
SW1: SPDT; SWITCH-SPDT-SMD
THM1: MAX31855; SO08
THMC: 1X2-3.5MM
TXLED: YELLOW; CHIPLED_0805
X1: 8MHz; NX5032

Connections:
3.3V: C4.1, C5.1, C7.1, LDO.5 (OUT), R4.2
+3V3: BMP1.2 (VDD), BMP1.3 (VDDIO), C2.1, C3.1, C11.1, C12.1, C13.1, C16.1, C17.1, C18.1, C19.1, C21.1, C22.1, C23.1, C24.1, C25.1, CDR.2, CON1.6, CON2.6, DHT1.1, EMBD.8, IC1.6 (UCAP), IC1.14 (VCC), IC1.24 (AVCC), IC1.34 (VCC1), IC1.42 (AREF), IC1.44 (AVCC1), IC2.15 (VDDTX), IC2.19 (VDDRX), IC2.20 (VDDPLL), IC2.25 (VDDOSC), IC2.28 (VDD), ISP-PWR.2, LCD.7, MICROSD.4 (VCC), NORDIC.2, OLEDADA.5, OLEDSD.2, R7.2, R8.2, R9.2, R10.1, R11.1, R12.1, RTC.2 (VCC), THM1.4 (VCC)
+5V: C10.1, D2.A, F2.2, IC1.7 (VBUS)
A0: CON1.4
A1: CON1.2
A2: CON2.2, CON2.4, LCD.4, NORDIC.4
A3: CON2.9, LCD.3
A4: CON2.7, LCD.2
A5: LCD.1, OLEDADA.3
CHARGE_STAT: LIPO.1 (STAT), RC.2
D0/RX: EMBD.5
D1/TX: EMBD.4
D4/A6: MICROSD.2 (CS)
D5*: LCD.5
D6*/A8: R11.2, THM1.6 (/CS)
D7/AIN0: DHT1.2, R10.2
E-CLK: IC2.3 (CLKOUT)
E-INT: IC2.4 (/INT)
GND: B1.2 (S), BATRTC.P$1 (-), BKOUT.1, BMP1.7 (GND), BTN.A, BTN.A' (P1), C1.2, C2.2, C3.2, C4.2, C5.2, C6.2, C7.2, C8.1, C9.1, C10.2, C11.2, C12.2, C13.2, C14.2, C15.2, C16.2, C17.2, C18.2, C19.2, C21.2, C22.2, C23.2, C24.2, C25.2, C26.2, C27.1, C28.1, CN1.GND, CON1.8, CON2.8, CX1.2, CX2.2, DHT1.4, EMBD.6, EXT-CHG.1, EXT-PWR1.1, EXT-PWR-F.1, IC1.5 (UGND), IC1.15 (GND), IC1.23 (GND1), IC1.35 (GND2), IC1.43 (GND3), IC2.2 (VSS), IC2.11 (VSSRX), IC2.18 (VSSTX), IC2.21 (VSSPLL), IC2.22 (VSSOSC), ICSP.6, LCD.8, LDO.2 (GND), LIPO.2 (VSS), MICROSD.6 (GND), MICROSD.GND1 (SHIELD), MICROSD.GND3 (SHIELD), MICROSD.P$1 (SHIELD), MICROSD.P$2 (SHIELD), NORDIC.1, OLEDADA.4, OLEDSD.1, PWR1.C, R1.1, R5.2, R6.1, R13.2, R14.1, R15.1, RJ1.G-, RJ1.GND, RJ1.SHIELD0, RJ1.SHIELD1, RJ1.Y-, RTC.5 (NC1), RTC.6 (NC2), RTC.7 (NC3), RTC.8 (NC4), RTC.9 (NC5), RTC.10 (NC6), RTC.11 (NC7), RTC.12 (NC8), RTC.13 (GND), THM1.1 (GND)
IO8/A9: IC2.9 (CS)
IO9*/A10: CDR.1, R13.1
IO10*/A11: CON1.9
IO11*: CON1.7
IO13*: BKOUT.2, LCD.6
IRQ: NORDIC.8
LEDA: REA.2, RJ1.G+
LEDB: REB.2, RJ1.Y+
MISO: CON1.5, CON2.5, EMBD.2, IC2.6 (SO), ICSP.1, MICROSD.7 (DO), NORDIC.7, THM1.7 (DO)
MOSI: CON1.3, CON2.3, EMBD.3, IC2.7 (SI), ICSP.4, MICROSD.3 (DI), NORDIC.6
unnamed: CN1.D+, R2.1
unnamed: IC1.3 (D-), R3.2
unnamed: IC1.4 (D+), R2.2
unnamed: CN1.D-, R3.1
unnamed: B1.1, R7.1
unnamed: C8.2, IC1.17 (XTAL1), X1.P$2
unnamed: C9.2, IC1.16 (XTAL2), X1.P$1
unnamed: PWR1.A, R4.1
unnamed: R5.1, TXLED.C
unnamed: R6.2, RXLED.C
unnamed: EXT-SWITCH.2, F1.2, SW1.2
unnamed: C27.2, RN1.5 (2), RN1.6 (2)
unnamed: IC2.26 (LEDB), REB.1
unnamed: C26.1, IC2.1 (VCAP)
unnamed: IC2.14 (RBIAS), R15.2
unnamed: CX1.1, EXTL.P$2 (2), IC2.24 (OSC2)
unnamed: CX2.1, EXTL.P$1 (1), IC2.23 (OSC1)
unnamed: IC2.27 (LEDA), REA.1
unnamed: BATRTC.P$2 (+), RTC.14 (VBAT)
unnamed: FB1.1, THMC.2
unnamed: C20.1, FB1.2, THM1.2 (T-)
unnamed: FB2.1, THMC.1
unnamed: C20.2, FB2.2, THM1.3 (T+)
unnamed: CHG1.C, RC.1
unnamed: LIPO.5 (PROG), R1.2
unnamed: D1.A, EXT-CHG.2
RAW: EXT-SWITCH.1, LDO.1 (IN), LDO.3 (EN), SW1.1 (O)
RAW1: ISP-PWR.1
RD+: IC2.13 (TPIN+), RJ1.RD+, RN1.4 (1)
RD-: IC2.12 (TPIN-), RJ1.RD-, RN1.3 (1)
RST: BTN.B (S), BTN.B' (S1), IC1.13 (/RESET), IC2.10 (RESET), ICSP.5
RTC-32KHZ: BKOUT.4, RTC.1 (32KHZ)
RTC-INT: BKOUT.5, RTC.3 (!INT/SQW)
RTC-RST: BKOUT.6, RTC.4 (!RST)
RXLED/SS: RXLED.A
SCK: CON1.1, CON2.1, EMBD.1, IC2.8 (SCK), ICSP.3, MICROSD.5 (SCK), NORDIC.5, R12.2, THM1.5 (SCK)
SCK1: R14.2
SCL: BKOUT.7, BMP1.5 (SCL), OLEDADA.2, OLEDSD.4, R8.1, RTC.16 (SCL)
SDA: BKOUT.8, BMP1.6 (SDA), OLEDADA.1, OLEDSD.3, R9.1, RTC.15 (SDA)
TCT: C28.2, L1.1, RJ1.P4, RN1.7 (2), RN1.8 (2)
TD+: IC2.17 (TPOUT+), RJ1.TD+, RN1.2 (1)
TD-: IC2.16 (TPOUT-), RJ1.TD-, RN1.1
TXLED: TXLED.A
VBATT: C6.1, EXT-PWR1.2, EXT-PWR-F.2, F1.1, LIPO.3 (VBAT)
VBUS: CN1.VBUS, F2.1
VCC: C1.1, C14.1, C15.1, CHG1.A, D1.C, D2.C, L1.2, LIPO.4 (VIN)
VIN: CON1.10, CON2.10, EMBD.7

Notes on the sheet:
Ethernet
LED
RST
D/C
DIN
CLK
VCC
GND
LCD (Nokia 5110)
RTC
Breakout
Raspberry Pi / Beagle Bone
Humidity
Pressure
Thermocouple
THMC
Max Voltage Input: 16VDC
Max Current Output: 500mA
2K for 500mA charging
10K for 100mA charging
power circuit from Fio
Photocell
Bypassing
BUTTON
OLM-REV-5
OLED / SEEED
OLED / Adafruit
uSD
Radio
resistors can range from 2.2k to 10k

Board: 2 copper layers, 93 parts (0 on the bottom side), 60 nets, no tracks yet.

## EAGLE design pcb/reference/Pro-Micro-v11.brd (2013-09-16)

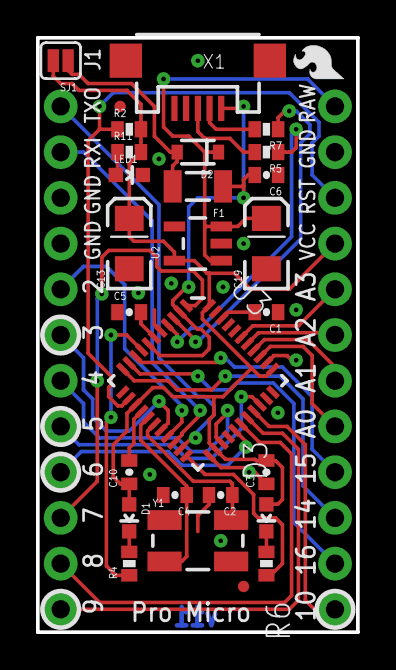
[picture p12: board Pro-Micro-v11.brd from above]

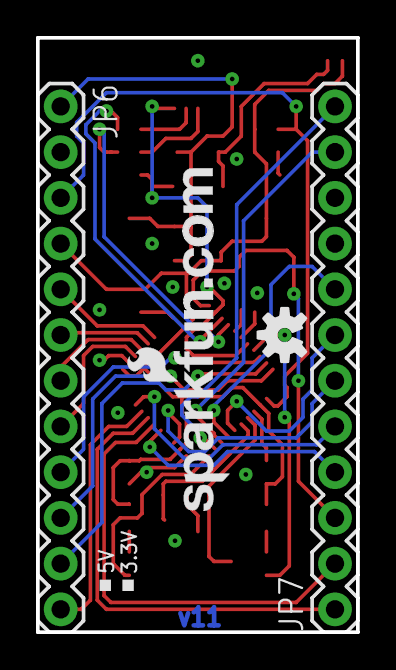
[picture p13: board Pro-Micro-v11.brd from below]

Board: 2 copper layers, 17.8 x 33.0 mm, 33 parts (4 on the bottom side), 37 nets.

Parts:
C1, C3: 0.1uF; 0402-CAP
C2, C4: 22pF; 0402-CAP
C5, C6, C10: 1uF; 0402-CAP
C13, C19: 10uF; EIA3216
D1: Yellow; LED-0603
D2: SOD-323
D3: Green; LED-0603
F1: 500mA; PTC-1206
JP1, JP2: FIDUCIALUFIDUCIAL; MICRO-FIDUCIAL
JP6, JP7: 1X12
LED1: Red; LED-0603
R2: 10K; 0402-RES
R4, R6: 330; 0402-RES
R5, R7: 22; 0402-RES
R11: 1K; 0402-RES
SJ1: Closed for 5V Board; SJ_2S
U2: MIC5219; SOT23-5
U3: ATMEGA32U4; QFN-44-NOPAD
U$1: LOGO-SFESK; SFE-LOGO-FLAME
U$3: OSHW-LOGOS; OSHW-LOGO-S
U$5: CREATIVE_COMMONS
U$11: LOGO-SFENEW; SFE-NEW-WEBLOGO
X1: USB-MICROB
Y1: 16MHz; CRYSTAL-SMD-5X3

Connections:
A0: JP6.8, U3.36
A1: JP6.7, U3.37
A2: JP6.6, U3.38
A3: JP6.5, U3.39
AREF: C1.2, U3.42
D2: JP7.8, U3.19
D3: JP7.7, U3.18
D4: JP7.6, U3.25
D5: JP7.5, U3.31
D6: JP7.4, U3.27
D7: JP7.3, U3.1
D8: JP7.2, U3.28
D9: JP7.1, U3.29
D10: JP6.12, U3.30
D17: R4.1, U3.8
D+: R5.1, U3.4
D-: R7.1, U3.3
GND: C1.1, C2.2, C3.1, C4.2, C5.1, C6.1, C10.2, C13.C, C19.C, JP6.2, JP7.9, JP7.10, LED1.C, U2.2, U3.5, U3.15, U3.23, U3.33, U3.35, U3.43, X1.GND
MISO: JP6.10, U3.11
MOSI: JP6.11, U3.10
unnamed: C4.1, U3.16, Y1.1
unnamed: C2.1, U3.17, Y1.3
unnamed: D2.2, F1.2, SJ1.1
unnamed: C5.2, U3.6
unnamed: D1.C, R4.2
unnamed: R7.2, X1.D-
unnamed: D3.C, R6.2
unnamed: R5.2, X1.D+
unnamed: LED1.A, R11.1
RAW: C19.A, D2.1, JP6.1, U2.1, U2.3
RESET: JP6.3, R2.1, U3.13
RXI: JP7.11, U3.20
SCK: JP6.9, U3.9
TXLED: R6.1, U3.22
TXO: JP7.12, U3.21
UVCC: C6.2, F1.1, U3.2, U3.7, X1.VBUS
VCC: C3.2, C10.1, C13.A, D1.A, D3.A, JP6.4, R2.2, R11.2, SJ1.2, U2.5, U3.14, U3.24, U3.34, U3.44

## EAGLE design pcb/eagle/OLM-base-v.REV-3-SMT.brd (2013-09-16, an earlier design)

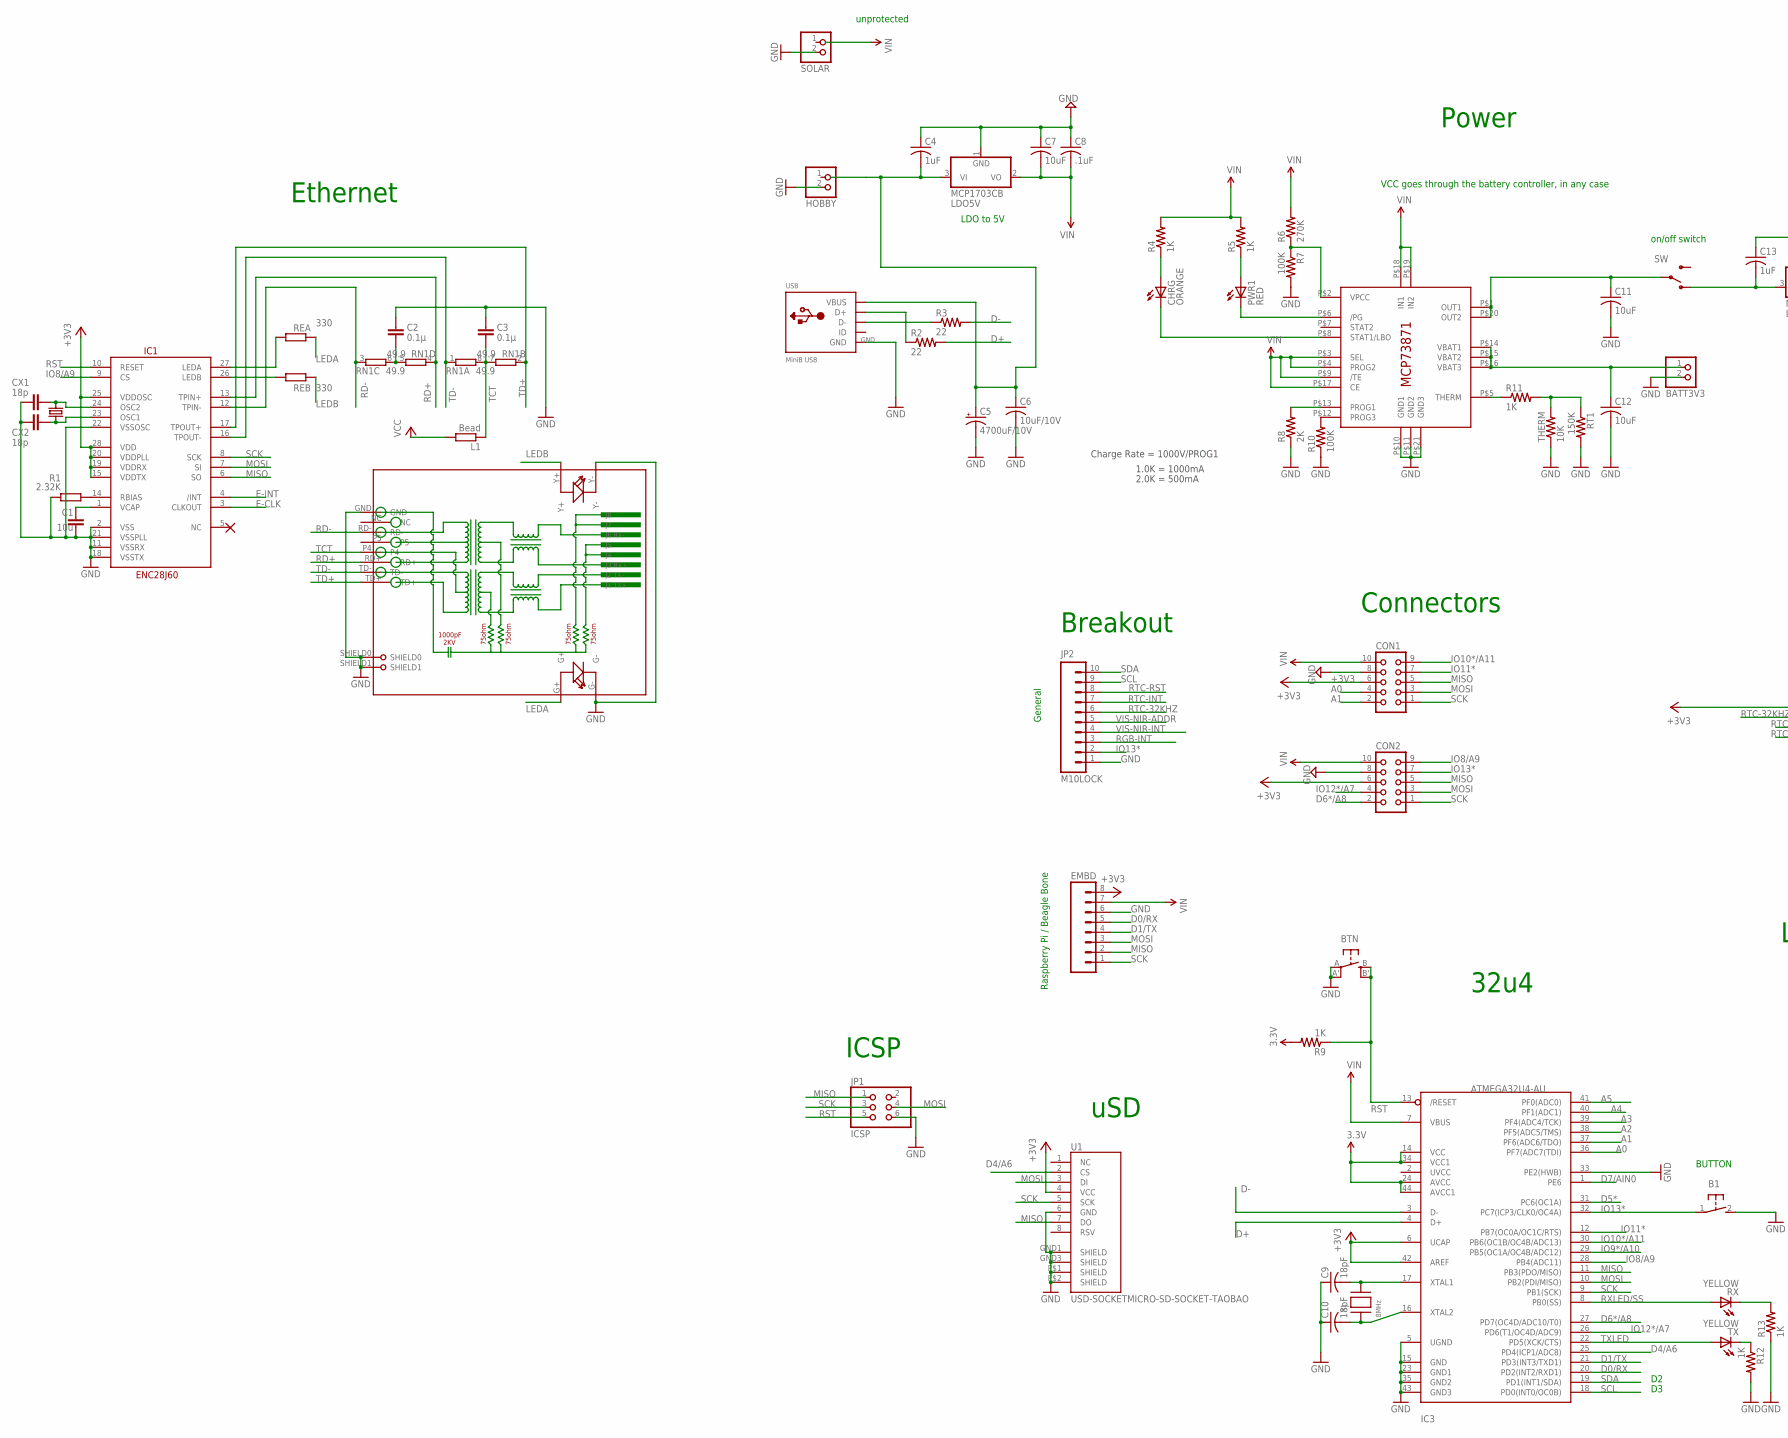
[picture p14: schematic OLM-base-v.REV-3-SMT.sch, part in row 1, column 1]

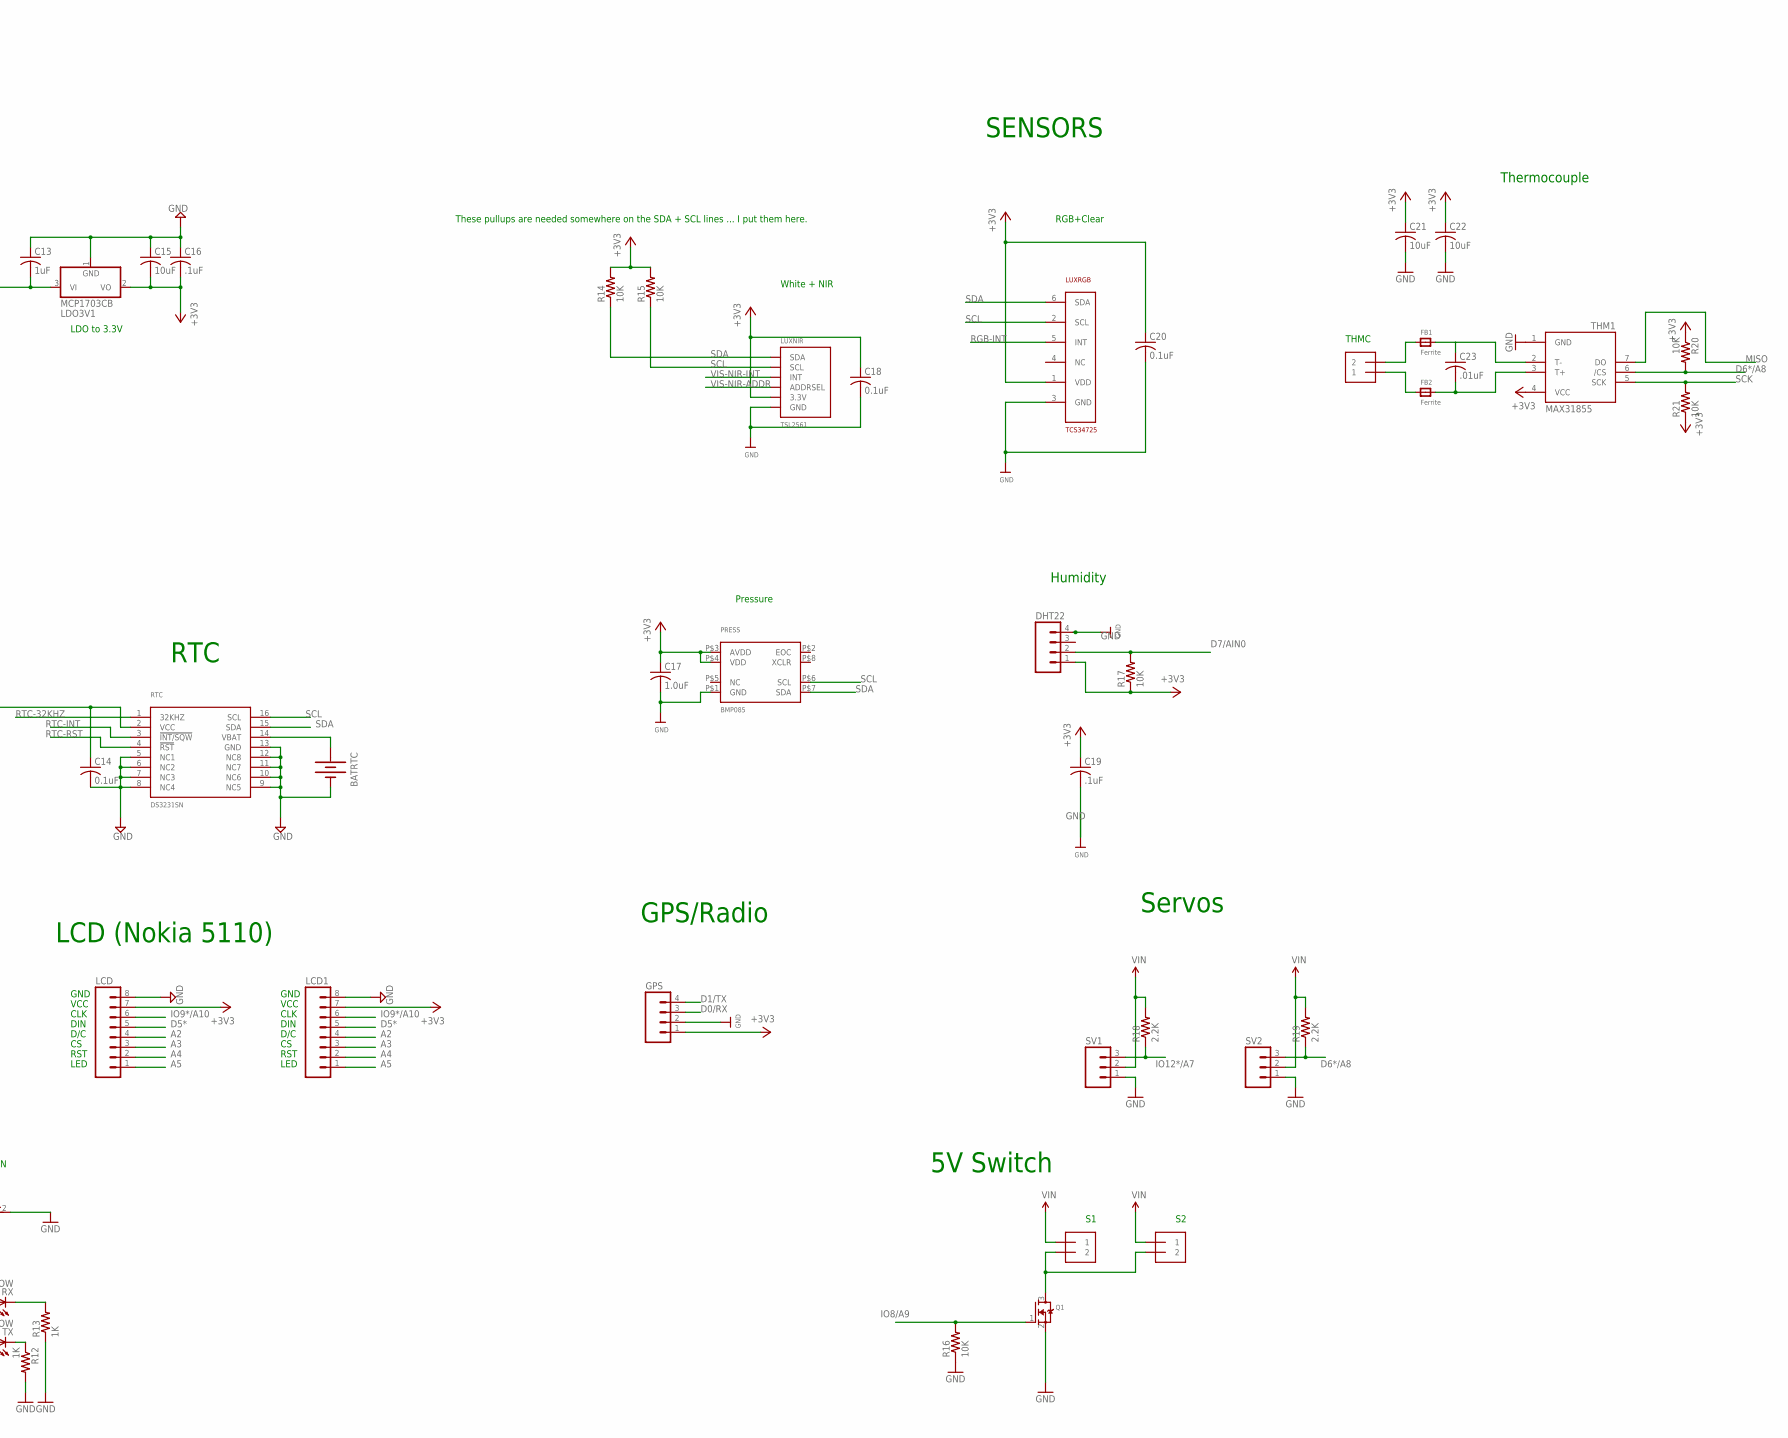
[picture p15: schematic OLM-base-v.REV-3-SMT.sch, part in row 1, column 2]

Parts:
B1: 31-XX; B3F-31XX
BATRTC: BATTERYBATTERY_12MM_SMT; BATTCON_12MM_SMT
BATT3V3: JST_2PIN-SMT-RA; JST-PH-2-SMT-RA
BTN: EVQQ2; EVQ-Q2
C1: 10u; C0805
C2, C3: 0.1µ; C0805
C4, C13: 1uF; C0805
C5: 4700uF/10V; E5-13
C6: 10uF/10V; C0805
C7, C11, C12, C15, C21, C22: 10uF; C0805
C8, C16, C19: .1uF; C0805
C9, C10: 18pF; C0805
C14, C18, C20: 0.1uF; C0805
C17: 1.0uF; C0805
C23: .01uF; C0805
CHRG: ORANGE; CHIP-LED0805
CON1, CON2: CON10L
CX1, CX2: 18p; C0805
DHT22: M04LOCK; 1X04_LOCK
EMBD: M08LOCK; 1X08_LOCK
EXTL: 25MHz; CRYSTAL-SMD-10.5X4.8-2PIN
FB1, FB2: Ferrite; _0805
GPS: M04LOCK; 1X04_LOCK
HOBBY: JST_2PIN-SMT-RA; JST-PH-2-SMT-RA
IC1: ENC28J60; SOIC28WLONG
IC2: MCP73871; QFN20_4MM
IC3: ATMEGA32U4-AU; TQFP44
JP1: ICSP; 2X03
JP2: M10LOCK; 1X10_LOCK
L1: Bead; R0805
LCD, LCD1: M08LOCK; 1X08_LOCK
LDO3V1, LDO5V: MCP1703CB; SOT23
LUXNIR: TSL2561; TSL2561_FN@1
LUXRGB: TCS34725; DFN-6
PRESS: BMP085
PWR1: RED; CHIP-LED0805
Q1: MOSFET-NREFLOW; SOT23
R1: 2.32K; R0805
R2, R3: 22; R0805
R4, R5, R9, R12, R13: 1K; R0805
R6: 270K; R0805
R7, R10: 100K; R0805
R8: 2K; 0805-THM
R11: 1K; M0805
R14, R15, R16, R17, R20, R21: 10K; R0805
R18, R19: 2.2K; R0805
REA: 330; R0805
REB: 330; R0805
RJ1: HR911105A
RN1: 49.9; EXB38V
RT1: 150K; R0805
RTC: DS3231SN; SO16W
RX: YELLOW; CHIPLED_0805
S1, S2: 1X2-3.5MM
SOLAR: JST_2PIN-SMT-RA; JST-PH-2-SMT-RA
SV1, SV2: M03PTH; 1X03
SW: SPDT; SWITCH-SPDT-SMD
THERM: 10K; 0805-THM
THM1: MAX31855; SO08
THMC: 1X2-3.5MM
TX: YELLOW; CHIPLED_0805
U1: USD-SOCKETMICRO-SD-SOCKET-TAOBAO; MICRO-SD-SOCKET-TAOBAO
USB: MiniB USB; USB-MINIB_LARGER
X1: 8MHz; NX5032

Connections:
+3V3: C14.1, C15.2, C16.2, C17.1, C18.1, C19.1, C20.1, C21.1, C22.1, CON1.6, CON2.6, DHT22.1, EMBD.8, GPS.1, IC1.15 (VDDTX), IC1.19 (VDDRX), IC1.20 (VDDPLL), IC1.25 (VDDOSC), IC1.28 (VDD), IC3.6 (UCAP), IC3.42 (AREF), LCD.7, LCD1.7, LDO3V1.2 (VO), LUXNIR.VDD (3.3V), LUXRGB.1 (VDD), PRESS.P$3 (AVDD), PRESS.P$4 (VDD), R14.2, R15.2, R17.1, R20.1, R21.1, RTC.2 (VCC), THM1.4 (VCC), U1.4 (VCC)
A0: CON1.4, IC3.36 (PF7(ADC7(TDI))
A1: CON1.2, IC3.37 (PF6(ADC6/TDO))
A2: IC3.38 (PF5(ADC5/TMS)), LCD.4, LCD1.4
A3: IC3.39 (PF4(ADC4/TCK)), LCD.3, LCD1.3
A4: IC3.40 (PF1(ADC1)), LCD.2, LCD1.2
A5: IC3.41 (PF0(ADC0)), LCD.1, LCD1.1
BATT: BATT3V3.1 (2), C12.1, IC2.P$14 (VBAT1), IC2.P$15 (VBAT2), IC2.P$16 (VBAT3)
D0/RX: EMBD.5, GPS.3, IC3.20 (PD2(INT2/RXD1))
D1/TX: EMBD.4, GPS.4, IC3.21 (PD3(INT3/TXD1))
D4/A6: IC3.25 (PD4(ICP1/ADC8)), U1.2 (CS)
D5*: IC3.31 (PC6(OC1A)), LCD.5, LCD1.5
D6*/A8: CON2.2, IC3.27 (PD7(OC4D/ADC10/T0)), R19.1, R20.2, SV2.3, THM1.6 (/CS)
D7/AIN0: DHT22.2, IC3.1 (PE6), R17.2
D+: IC3.4 (D+), R2.2
D-: IC3.3 (D-), R3.2
E-CLK: IC1.3 (CLKOUT)
E-INT: IC1.4 (/INT)
GND: B1.2 (S), BATRTC.P$1 (-), BATT3V3.2 (1), BTN.A, BTN.A' (P1), C1.2, C2.1, C3.1, C4.1, C5.-, C6.2, C7.1, C8.1, C9.1, C10.1, C11.2, C12.2, C13.1, C14.2, C15.1, C16.1, C17.2, C18.2, C19.2, C20.2, C21.2, C22.2, CON1.8, CON2.8, CX1.2, CX2.2, DHT22.4, EMBD.6, GPS.2, HOBBY.2 (1), IC1.2 (VSS), IC1.11 (VSSRX), IC1.18 (VSSTX), IC1.21 (VSSPLL), IC1.22 (VSSOSC), IC2.P$10 (GND1), IC2.P$11 (GND2), IC2.P$21 (GND3), IC3.5 (UGND), IC3.15 (GND), IC3.23 (GND1), IC3.33 (PE2(HWB)), IC3.35 (GND2), IC3.43 (GND3), JP1.6, JP2.1, LCD.8, LCD1.8, LDO3V1.1 (GND), LDO5V.1 (GND), LUXNIR.VSS (GND), LUXRGB.3 (GND), PRESS.P$1 (GND), Q1.2 (S), R1.1, R7.2, R8.1, R10.1, R12.2, R13.1, R16.1, RJ1.G-, RJ1.GND, RJ1.SHIELD0, RJ1.SHIELD1, RJ1.Y-, RT1.2, RTC.5 (NC1), RTC.6 (NC2), RTC.7 (NC3), RTC.8 (NC4), RTC.9 (NC5), RTC.10 (NC6), RTC.11 (NC7), RTC.12 (NC8), RTC.13 (GND), SOLAR.2 (1), SV1.1, SV2.1, THERM.1, THM1.1 (GND), U1.6 (GND), U1.GND1 (SHIELD), U1.GND3 (SHIELD), U1.P$1 (SHIELD), U1.P$2 (SHIELD), USB.GND
HIGH-CURRENT: Q1.3 (D), S1.2, S2.2
IO8/A9: CON2.9, IC1.9 (CS), IC3.28 (PB4(ADC11)), Q1.1 (G), R16.2
IO9*/A10: IC3.29 (PB5(OC1A/OC4B/ADC12)), LCD.6, LCD1.6
IO10*/A11: CON1.9, IC3.30 (PB6(OC1B/OC4B/ADC13))
IO11*: CON1.7, IC3.12 (PB7(OC0A/OC1C/RTS))
IO12*/A7: CON2.4, IC3.26 (PD6(T1/OC4D/ADC9)), R18.1, SV1.3
IO13*: B1.1, CON2.7, IC3.32 (PC7(ICP3/CLK0/OC4A))
LEDA: REA.2, RJ1.G+
LEDB: REB.2, RJ1.Y+
MISO: CON1.5, CON2.5, EMBD.2, IC1.6 (SO), IC3.11 (PB3(PDO/MISO)), JP1.1, THM1.7 (DO), U1.7 (DO)
MOSI: CON1.3, CON2.3, EMBD.3, IC1.7 (SI), IC3.10 (PB2(PDI/MISO)), JP1.4, U1.3 (DI)
unnamed: BATRTC.P$2 (+), RTC.14 (VBAT)
unnamed: IC1.27 (LEDA), REA.1
unnamed: FB1.1, THMC.2
unnamed: C23.1, FB1.2, THM1.2 (T-)
unnamed: FB2.1, THMC.1
unnamed: C23.2, FB2.2, THM1.3 (T+)
unnamed: C9.2, IC3.17 (XTAL1), X1.P$2
unnamed: C10.2, IC3.16 (XTAL2), X1.P$1
unnamed: C2.2, RN1.5 (2), RN1.6 (2)
unnamed: R12.1, TX.C
unnamed: R13.2, RX.C
unnamed: IC1.26 (LEDB), REB.1
unnamed: C1.1, IC1.1 (VCAP)
unnamed: IC1.14 (RBIAS), R1.2
unnamed: CX1.1, EXTL.P$2 (2), IC1.24 (OSC2)
unnamed: CX2.1, EXTL.P$1 (1), IC1.23 (OSC1)
unnamed: IC2.P$2 (VPCC), R6.1, R7.1
unnamed: IC2.P$6 (/PG), PWR1.C
unnamed: C4.2, C5.+, C6.1, LDO5V.3 (VI), USB.VBUS
unnamed: CHRG.C, IC2.P$8 (STAT1/LBO)
unnamed: CHRG.A, R4.1
unnamed: PWR1.A, R5.1
unnamed: IC2.P$12 (PROG3), R10.2
unnamed: IC2.P$13 (PROG1), R8.2
unnamed: C11.1, IC2.P$1 (OUT1), IC2.P$20 (OUT2), SW.2
unnamed: IC2.P$5 (THERM), R11.1
unnamed: R11.2, RT1.1, THERM.2
unnamed: R2.1, USB.D+
unnamed: R3.1, USB.D-
unnamed: C13.2, LDO3V1.3 (VI)
RD+: IC1.13 (TPIN+), RJ1.RD+, RN1.4 (1)
RD-: IC1.12 (TPIN-), RJ1.RD-, RN1.3 (1)
RGB-INT: LUXRGB.5 (INT)
RST: BTN.B (S), BTN.B' (S1), IC1.10 (RESET), IC3.13 (/RESET), JP1.5, R9.1
RTC-32KHZ: RTC.1 (32KHZ)
RTC-INT: RTC.3 (!INT/SQW)
RTC-RST: RTC.4 (!RST)
RXLED/SS: IC3.8 (PB0(SS)), RX.A
SCK: CON1.1, CON2.1, EMBD.1, IC1.8 (SCK), IC3.9 (PB1(SCK)), JP1.3, R21.2, THM1.5 (SCK), U1.5 (SCK)
SCL: IC3.18 (PD0(INT0/OC0B)), JP2.9, LUXNIR.CLK (SCL), LUXRGB.2 (SCL), PRESS.P$6 (SCL), R15.1, RTC.16 (SCL)
SDA: IC3.19 (PD1(INT1/SDA)), JP2.10, LUXNIR.DATA (SDA), LUXRGB.6 (SDA), PRESS.P$7 (SDA), R14.1, RTC.15 (SDA)
TCT: C3.2, L1.1, RJ1.P4, RN1.7 (2), RN1.8 (2)
TD+: IC1.17 (TPOUT+), RJ1.TD+, RN1.2 (1)
TD-: IC1.16 (TPOUT-), RJ1.TD-, RN1.1
TXLED: IC3.22 (PD5(XCK/CTS)), TX.A
VCC: IC3.14 (VCC), IC3.24 (AVCC), IC3.34 (VCC1), IC3.44 (AVCC1), L1.2, R9.2
VIN: C7.2, C8.2, CON1.10, CON2.10, EMBD.7, IC2.P$3 (SEL), IC2.P$4 (PROG2), IC2.P$9 (/TE), IC2.P$17 (CE), IC2.P$18 (IN1), IC2.P$19 (IN2), IC3.7 (VBUS), LDO5V.2 (VO), R4.2, R5.2, R6.2, R18.2, R19.2, S1.1, S2.1, SV1.2, SV2.2
VIS-NIR-ADDR: LUXNIR.ADR (ADDRSEL)
VIS-NIR-INT: LUXNIR.INT

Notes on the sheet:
Power
uSD
32u4
Connectors
ICSP
Ethernet
Breakout
RTC
RGB+Clear
White + NIR
Pressure
Charge Rate = 1000V/PROG1
1.0K = 1000mA
2.0K = 500mA
Humidity
on/off switch
VCC goes through the battery controller, in any case
SENSORS
These pullups are needed somewhere on the SDA + SCL lines ... I put them here.
LED
RST
D/C
DIN
CLK
VCC
GND
Thermocouple
LDO to 5V
LDO to 3.3V
General
Raspberry Pi / Beagle Bone
unprotected
BUTTON
LCD (Nokia 5110)
GPS/Radio
Servos
5V Switch
THMC

Board: 2 copper layers, 95 parts (0 on the bottom side), 71 nets, no tracks yet.

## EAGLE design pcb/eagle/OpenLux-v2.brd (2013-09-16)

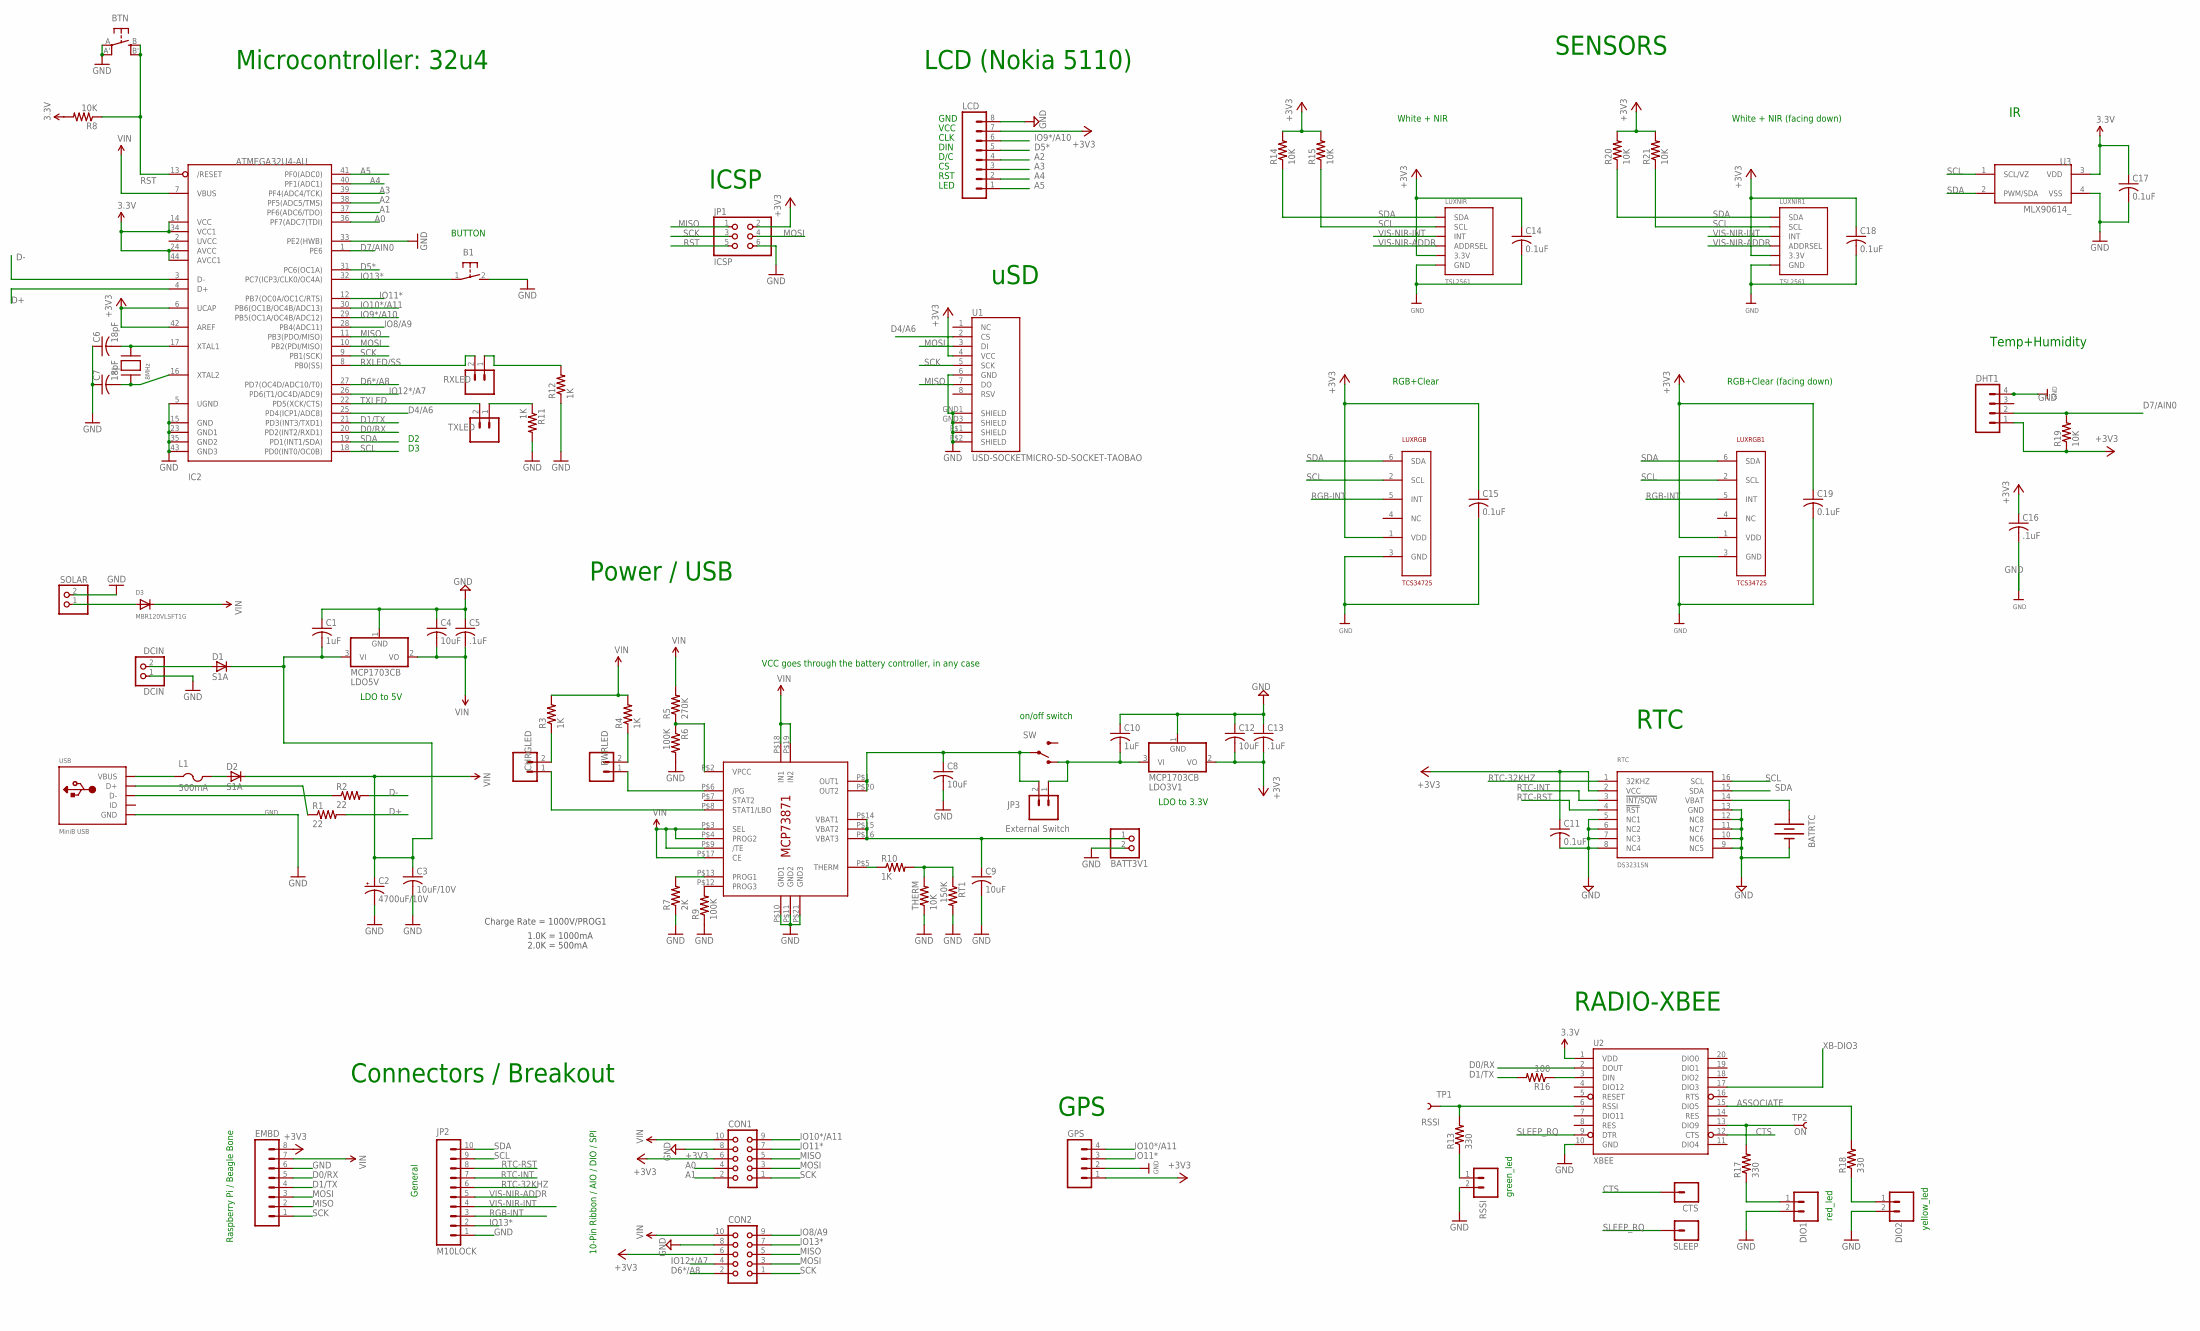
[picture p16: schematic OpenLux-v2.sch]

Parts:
B1: 31-XX; B3F-31XX
BATRTC: BATTERYBATTERY_12MM_SMT; BATTCON_12MM_SMT
BATT3V1: JST_2PIN-SMT-RA; JST-PH-2-SMT-RA
BTN: EVQQ2; EVQ-Q2
C1, C10: 1uF; C0805
C2: 4700uF/10V; E5-13
C3: 10uF/10V; C0805
C4, C8, C9, C12: 10uF; C0805
C5, C13, C16: .1uF; C0805
C6, C7: 18pF; C0805
C11, C14, C15, C17, C18, C19: 0.1uF; C0805
CHRGLED: M02PTH; 1X02
CON1, CON2: CON10L
CTS: M01PTH; 1X01
D1, D2: S1A; DO-214AC
D3: MBR120VLSFT1G; SOD-123
DCIN: DCIN; 1X02_OVAL
DHT1: M04LOCK; 1X04_LOCK
DIO1, DIO2: M02PTH; 1X02
EMBD: M08LOCK; 1X08_LOCK
GPS: M04LOCK; 1X04_LOCK
IC1: MCP73871; QFN20_4MM
IC2: ATMEGA32U4-AU; TQFP44
JP1: ICSP; 2X03
JP2: M10LOCK; 1X10_LOCK
JP3: External Switch; 1X02
L1: 500mA; R1206
LCD: M08LOCK; 1X08_LOCK
LDO3V1, LDO5V: MCP1703CB; SOT23
LUXNIR, LUXNIR1: TSL2561; TSL2561_FN@1
LUXRGB, LUXRGB1: TCS34725; DFN-6
PWRLED: M02PTH; 1X02
R1, R2: 22; R0805
R3, R4, R11, R12: 1K; R0805
R5: 270K; R0805
R6, R9: 100K; R0805
R7: 2K; 0805-THM
R8, R14, R15, R19, R20, R21: 10K; R0805
R10: 1K; M0805
R13, R17, R18: 330; R0805
R16: 100; R0805
RSSI: M02PTH; 1X02
RT1: 150K; R0805
RTC: DS3231SN; SO16W
RXLED: M02PTH; 1X02
SLEEP: M01PTH; 1X01
SOLAR: JST_2PIN-SMT-RA; JST-PH-2-SMT-RA
SW: SPDT; SWITCH-SPDT-SMD
THERM: 10K; 0805-THM
TP1: RSSI; PAD.03X.05
TP2: ON; PAD.03X.05
TXLED: M02PTH; 1X02
U1: USD-SOCKETMICRO-SD-SOCKET-TAOBAO; MICRO-SD-SOCKET-TAOBAO
U2: XBEE; XBEE-SMD
U3: MLX90614_; TO-39
USB: MiniB USB; USB-MINIB_LARGER
X1: 8MHz; NX5032

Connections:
3.3V: C17.1, U2.1 (VDD), U3.3 (VDD)
+3V3: C11.1, C12.2, C13.2, C14.1, C15.1, C16.1, C18.1, C19.1, CON1.6, CON2.6, DHT1.1, EMBD.8, GPS.1, IC2.6 (UCAP), IC2.42 (AREF), JP1.2, LCD.7, LDO3V1.2 (VO), LUXNIR.VDD (3.3V), LUXNIR1.VDD (3.3V), LUXRGB.1 (VDD), LUXRGB1.1 (VDD), R14.2, R15.2, R19.1, R20.2, R21.2, RTC.2 (VCC), U1.4 (VCC)
A0: CON1.4, IC2.36 (PF7(ADC7(TDI))
A1: CON1.2, IC2.37 (PF6(ADC6/TDO))
A2: IC2.38 (PF5(ADC5/TMS)), LCD.4
A3: IC2.39 (PF4(ADC4/TCK)), LCD.3
A4: IC2.40 (PF1(ADC1)), LCD.2
A5: IC2.41 (PF0(ADC0)), LCD.1
ASSOCIATE: R18.2, U2.15 (DIO5)
BATT: BATT3V1.1 (2), C9.1, IC1.P$14 (VBAT1), IC1.P$15 (VBAT2), IC1.P$16 (VBAT3)
CTS: CTS.1, U2.12 (CTS)
D0/RX: EMBD.5, IC2.20 (PD2(INT2/RXD1)), U2.2 (DOUT)
D1/TX: EMBD.4, IC2.21 (PD3(INT3/TXD1)), R16.2
D4/A6: IC2.25 (PD4(ICP1/ADC8)), U1.2 (CS)
D5*: IC2.31 (PC6(OC1A)), LCD.5
D6*/A8: CON2.2, IC2.27 (PD7(OC4D/ADC10/T0))
D7/AIN0: DHT1.2, IC2.1 (PE6), R19.2
D+: IC2.4 (D+), R1.2
D-: IC2.3 (D-), R2.2
GND: B1.2 (S), BATRTC.P$1 (-), BATT3V1.2 (1), BTN.A, BTN.A' (P1), C1.1, C2.-, C3.2, C4.1, C5.1, C6.1, C7.1, C8.2, C9.2, C10.1, C11.2, C12.1, C13.1, C14.2, C15.2, C16.2, C17.2, C18.2, C19.2, CON1.8, CON2.8, DCIN.1, DHT1.4, DIO1.2, DIO2.2, EMBD.6, GPS.2, IC1.P$10 (GND1), IC1.P$11 (GND2), IC1.P$21 (GND3), IC2.5 (UGND), IC2.15 (GND), IC2.23 (GND1), IC2.33 (PE2(HWB)), IC2.35 (GND2), IC2.43 (GND3), JP1.6, JP2.1, LCD.8, LDO3V1.1 (GND), LDO5V.1 (GND), LUXNIR.VSS (GND), LUXNIR1.VSS (GND), LUXRGB.3 (GND), LUXRGB1.3 (GND), R6.2, R7.1, R9.1, R11.2, R12.1, RSSI.2, RT1.2, RTC.5 (NC1), RTC.6 (NC2), RTC.7 (NC3), RTC.8 (NC4), RTC.9 (NC5), RTC.10 (NC6), RTC.11 (NC7), RTC.12 (NC8), RTC.13 (GND), SOLAR.2 (1), THERM.1, U1.6 (GND), U1.GND1 (SHIELD), U1.GND3 (SHIELD), U1.P$1 (SHIELD), U1.P$2 (SHIELD), U2.10 (GND), U3.4 (VSS), USB.GND
IO8/A9: CON2.9, IC2.28 (PB4(ADC11))
IO9*/A10: IC2.29 (PB5(OC1A/OC4B/ADC12)), LCD.6
IO10*/A11: CON1.9, GPS.4, IC2.30 (PB6(OC1B/OC4B/ADC13))
IO11*: CON1.7, GPS.3, IC2.12 (PB7(OC0A/OC1C/RTS))
IO12*/A7: CON2.4, IC2.26 (PD6(T1/OC4D/ADC9))
IO13*: B1.1, CON2.7, IC2.32 (PC7(ICP3/CLK0/OC4A)), JP2.2
MISO: CON1.5, CON2.5, EMBD.2, IC2.11 (PB3(PDO/MISO)), JP1.1, U1.7 (DO)
MOSI: CON1.3, CON2.3, EMBD.3, IC2.10 (PB2(PDI/MISO)), JP1.4, U1.3 (DI)
unnamed: BATRTC.P$2 (+), RTC.14 (VBAT)
unnamed: R17.2, TP2.P$1, U2.13 (DIO9)
unnamed: R13.1, RSSI.1
unnamed: R13.2, TP1.P$1, U2.6 (RSSI)
unnamed: R16.1, U2.3 (DIN)
unnamed: DIO1.1, R17.1
unnamed: D1.A, DCIN.2
unnamed: C6.2, IC2.17 (XTAL1), X1.P$2
unnamed: C7.2, IC2.16 (XTAL2), X1.P$1
unnamed: R11.1, TXLED.1
unnamed: R12.2, RXLED.1
unnamed: L1.1, USB.VBUS
unnamed: DIO2.1, R18.1
unnamed: IC1.P$2 (VPCC), R5.1, R6.1
unnamed: IC1.P$6 (/PG), PWRLED.1
unnamed: D3.A, SOLAR.1 (2)
unnamed: D2.A, L1.2
unnamed: CHRGLED.1, IC1.P$8 (STAT1/LBO)
unnamed: CHRGLED.2, R3.1
unnamed: PWRLED.2, R4.1
unnamed: IC1.P$12 (PROG3), R9.2
unnamed: IC1.P$13 (PROG1), R7.2
unnamed: C8.1, IC1.P$1 (OUT1), IC1.P$20 (OUT2), JP3.2, SW.2
unnamed: IC1.P$5 (THERM), R10.1
unnamed: R10.2, RT1.1, THERM.2
unnamed: R1.1, USB.D+
unnamed: R2.1, USB.D-
unnamed: C10.2, JP3.1, LDO3V1.3 (VI), SW.1 (O)
RGB-INT: JP2.3, LUXRGB.5 (INT), LUXRGB1.5 (INT)
RST: BTN.B (S), BTN.B' (S1), IC2.13 (/RESET), JP1.5, R8.1
RTC-32KHZ: JP2.6, RTC.1 (32KHZ)
RTC-INT: JP2.7, RTC.3 (!INT/SQW)
RTC-RST: JP2.8, RTC.4 (!RST)
RXLED/SS: IC2.8 (PB0(SS)), RXLED.2
SCK: CON1.1, CON2.1, EMBD.1, IC2.9 (PB1(SCK)), JP1.3, U1.5 (SCK)
SCL: IC2.18 (PD0(INT0/OC0B)), JP2.9, LUXNIR.CLK (SCL), LUXNIR1.CLK (SCL), LUXRGB.2 (SCL), LUXRGB1.2 (SCL), R15.1, R21.1, RTC.16 (SCL), U3.1 (SCL/VZ)
SDA: IC2.19 (PD1(INT1/SDA)), JP2.10, LUXNIR.DATA (SDA), LUXNIR1.DATA (SDA), LUXRGB.6 (SDA), LUXRGB1.6 (SDA), R14.1, R20.1, RTC.15 (SDA), U3.2 (PWM/SDA)
SLEEP_RQ: SLEEP.1, U2.9 (DTR)
TXLED: IC2.22 (PD5(XCK/CTS)), TXLED.2
VCC: IC2.14 (VCC), IC2.24 (AVCC), IC2.34 (VCC1), IC2.44 (AVCC1), R8.2
VIN: C1.2, C2.+, C3.1, C4.2, C5.2, CON1.10, CON2.10, D1.C, D2.C, D3.C, EMBD.7, IC1.P$3 (SEL), IC1.P$4 (PROG2), IC1.P$9 (/TE), IC1.P$17 (CE), IC1.P$18 (IN1), IC1.P$19 (IN2), IC2.7 (VBUS), LDO5V.2 (VO), LDO5V.3 (VI), R3.2, R4.2, R5.2
VIS-NIR-ADDR: JP2.5, LUXNIR.ADR (ADDRSEL), LUXNIR1.ADR (ADDRSEL)
VIS-NIR-INT: JP2.4, LUXNIR.INT, LUXNIR1.INT
XB-DIO3: U2.17 (DIO3)

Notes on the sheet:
Power / USB
uSD
Microcontroller: 32u4
Connectors / Breakout
ICSP
RTC
RGB+Clear
White + NIR
Charge Rate = 1000V/PROG1
1.0K = 1000mA
2.0K = 500mA
Temp+Humidity
on/off switch
VCC goes through the battery controller, in any case
SENSORS
LED
RST
D/C
DIN
CLK
VCC
GND
LDO to 5V
LDO to 3.3V
General
Raspberry Pi / Beagle Bone
BUTTON
LCD (Nokia 5110)
GPS
red_led
yellow_led
green_led
RADIO-XBEE
10-Pin Ribbon / AIO / DIO / SPI
RGB+Clear (facing down)
White + NIR (facing down)

Board: 2 copper layers, 87 parts (3 on the bottom side), 71 nets, no tracks yet.

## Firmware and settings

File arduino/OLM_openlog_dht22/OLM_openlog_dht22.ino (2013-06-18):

// Simple demo for feeding some random data to Open-Log
 
// 2013-06-06 http://opensource.org/licenses/mit-license.php
 
#include <EtherCard.h>
 
// change these settings to match your own setup
 
#define FEED "18" // change this to the feed you'd like to update
#define APIKEY "bananas" // your secret key.  this is the only secret that currently works :)
 
#include "DHT.h"
 
#define DHTPIN 3 // choose a digital pin -
#define DHTTYPE DHT22   

 int waitInterval=30;
 
DHT dht(DHTPIN, DHTTYPE);
 
 
static void my_result_cb (byte status, word off, word len) {
Serial.print("<<< reply ");
Serial.println(" ms");
Serial.println((const char*) Ethernet::buffer + off);
}
 
// from https://github.com/jcw/ethercard/blob/master/examples/pachube/pachube.ino
 
// ethernet interface mac address, must be unique on the LAN
byte mymac[] = { 0x74,0x69,0x69,0x2D,0x30,0x31 };
 
char website[] PROGMEM = "open-log.pvos.org";
 
byte Ethernet::buffer[700];
uint32_t timer;
Stash stash;
 
void setup () {
  
  dht.begin();
  
  
  Serial.begin(57600);
  Serial.println("\n[webClient]");
 
  startEthernet();
}
 
void loop () {
  ether.packetLoop(ether.packetReceive());
  
  if (millis() > timer) {
    timer = millis() + waitInterval*1000;
    
    
    
      float h = dht.readHumidity();
  float t = dht.readTemperature();
  
  Serial.print("t_ambient=");
  Serial.println(t);
  Serial.print("h=");
  Serial.println(h);
  
    float temperature = t;
 
    char tmp[10];
    char field1[] = "temp1";
    
    //usage of dtostrf(floatVar, minStringWidthIncDecimalPoint, numVarsAfterDecimal, charBuf);
    dtostrf(temperature,1,2, tmp);
    char buffer [100];
    sprintf(buffer,"feedID=%s&secretKey=%s&field1=%s&val1=%s",FEED, APIKEY, field1, tmp);
               
    //http://open-log.pvos.org/senddata?feedID=3&secretKey=bananas&field1=temp1&val1=3.
    //ether.browseUrl(PSTR("/senddata?"),"feedID=4&secretKey=bananas&field1=temp1&val1=3.03",website,my_result_cb);
    
    ether.browseUrl(PSTR("/senddata?"),buffer,website,my_result_cb);
 
  }
}

void startEthernet()
{
  
  if (ether.begin(sizeof Ethernet::buffer, mymac) == 0) 
    Serial.println( "Failed to access Ethernet controller");
  if (!ether.dhcpSetup())
    Serial.println("DHCP failed");
 
  ether.printIp("IP:  ", ether.myip);
  ether.printIp("GW:  ", ether.gwip);  
  ether.printIp("DNS: ", ether.dnsip);  
 
  if (!ether.dnsLookup(website))
    Serial.println("DNS failed");
    
  ether.printIp("SRV: ", ether.hisip);
  
}

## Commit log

2013-06-24 added REVB sensor board schematic
    [OLM-periph-probe+ambientREVB.sch, OpenSprinkler_v14.sch, STA540 Audio Amp v11.brd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]
2013-06-24 added pic of REVB sensor board
2013-06-24 added boost version of sensor board
    [OLM-periph-probe+ambient-boostREVB.sch]
2013-07-02 added env sensor
    [OLM-env-sensor-REVD.brd, OLM-env-sensor-REVD.sch]
2013-07-02 edited env sensor board
    [OLM-env-sensor-REVD.brd, OLM-env-sensor-REVD.sch]
2013-07-05 added flora-based OLM-base
    [OLM-base-flora.brd, OLM-base-flora.sch]
2013-07-08 added thermocouple schematic
    [OLM-thermocouple.sch]
2013-07-09 added some details
    [OLM-base-flora.brd, OLM-base-flora.sch, OLM-base_v.REVG.brd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]
2013-07-09 made some changes
    [OLM-base-flora.brd, OLM-base-flora.sch, OLM-thermocouple.brd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]
2013-07-09 wrapped up schematic
    [OLM-base-flora.brd, OLM-base-flora.sch]
2013-07-09 made changes
    [OLM-base_v.REVG.brd, OLM-base_v.REVG.sch]
2013-07-09 added schematics imagery
2013-07-09 added sensor board schematics
    [OLM-sensorBoardA.brd, OLM-sensorBoardA.sch]
2013-07-09 added smt
    [OLM-base-v.REVH-SMT.brd, OLM-base-v.REVH-SMT.sch]
2013-07-11 rewired surface mount version
    [OLM-base-v.REVH-SMT.brd, OLM-base-v.REVH-SMT.sch]
2013-07-11 rewired OLM-base-REVG
    [OLM-base_v.REVG.brd, OLM-base_v.REVG.sch]
2013-07-11 made sensor board
    [OLM-sensorBoardA.brd]
2013-07-13 fixed breakouts by adding reset pin
    [OLM-base-v.REVH-SMT.brd, OLM-base-v.REVH-SMT.sch, OLM-base_v.REVG.brd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]
2013-07-13 removed pin labels on bottom of board to satisfy seeed design rules
    [OLM-base-v.REVH-SMT.brd, OLM-base_v.REVG.brd]
2013-07-26 added changes
    [OLM-base-v.REV-I-SMT.brd, OLM-base-v.REV-I-SMT.sch]
2013-07-30 added schematic
    [OLM-base-v.REV-I-SMT.brd, OLM-base-v.REV-I-SMT.sch]
2013-08-15 added rui's fixes
    [OLM-base-v.REV-2-SMT.sch]
2013-08-16 added sub-schematics
2013-08-21 updated schematic
    [OLM-base-v.REV-2-SMT.sch]
2013-08-25 updated design
    [OLM-base-v.REV-2-SMT.sch]
2013-08-25 fixed design
    [OLM-base-v.REV-2-SMT.brd, OLM-base-v.REV-2-SMT.sch]
2013-08-25 more pcb changes
    [OLM-base-v.REV-3-SMT.brd, OLM-base-v.REV-3-SMT.sch]
2013-08-26 updated layout
    [OLM-base-v.REV-3-SMT.brd, OLM-base-v.REV-3-SMT.sch]
2013-08-26 added pic of schematic
2013-08-26 added board image
2013-09-12 added OpenLux board
    [Fio-v30.brd, Fio-v30.sch, OpenLux-v2.brd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]
2013-09-12 added olm4
    [OLM-base-v.REV-4-SMT.brd, OLM-base-v.REV-4-SMT.sch]
2013-09-12 added downward-facing light sensors
2013-09-16 added some schematics
    [BMP180 Breakout PCB Rev B.brd, BMP180 Breakout PCB Rev B.sch, BMP180 Breakout PCB.brd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]
2013-09-16 added in various lipo options
    [OLM-REV-5-SMT.sch]
2013-09-17 added stuff
    [OLM-REV-5-SMT.brd, OLM-REV-5-SMT.sch]
2013-09-18 added schematic and board images
    [OLM-REV-5-SMT.brd, OLM-REV-5-SMT.sch]
2013-09-20 new olm version with fix
    [OLM7.brd, OLM7.sch]
2014-04-05 added a VUSB version of the OLM
    [open-lab-VUSB-A.brd, open-lab-VUSB-A.sch]
2014-04-06 fixed some pin assignments
    [open-lab-VUSB-A.brd, open-lab-VUSB-A.sch]
2014-04-07 minor silkscreen fixes
    [open-lab-VUSB-A.brd]

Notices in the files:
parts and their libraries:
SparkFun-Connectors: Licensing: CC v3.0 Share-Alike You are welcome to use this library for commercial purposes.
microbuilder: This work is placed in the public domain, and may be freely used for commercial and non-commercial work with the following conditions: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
